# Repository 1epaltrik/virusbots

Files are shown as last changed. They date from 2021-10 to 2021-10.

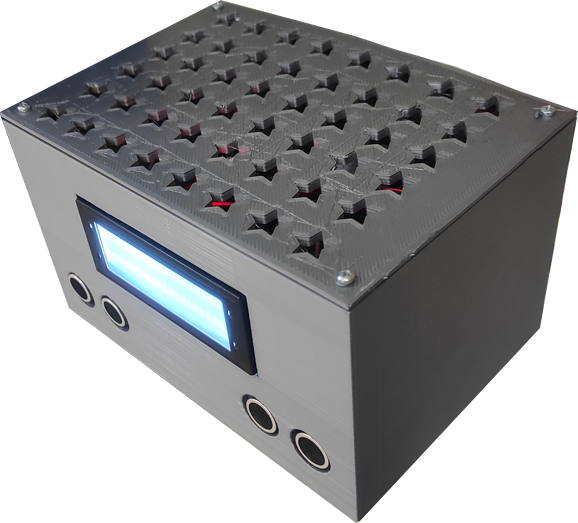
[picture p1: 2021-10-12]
VirusBots Case.png

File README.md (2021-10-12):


<p style="text-align: justify;">Το έργο μας αποτελείται από διάφορες τεχνολογίες οι οποίες όλες μαζί αποτελούν ένα σύστημα καταγραφής βεβαρημένης ατμόσφαιρας, που μπορεί να συμβάλλει στην παρακολούθηση του ιικού φορτίου στις σχολικές αίθουσες. Συγκεκριμένα οι επιμέρους λειτουργίες του είναι:</p>

<ul>
 	<li><strong> </strong><strong>Καταμέτρηση ατόμων</strong></li>
</ul>

<p style="text-align: justify; padding-left: 40px;">Καταγράφει πόσοι μαθητές βρίσκονται σε κάθε αίθουσα την κάθε στιγμή (ουσιαστικά χρησιμοποιείται ως παρουσιολόγιο). Χρησιμοποιήσαμε δύο Αισθητήρες Απόστασης Υπερήχων οι οποίοι συνδέονται σε ένα Arduino Mega. Ο Α αισθητήρας τοποθετήθηκε στην έξω πλευρά της τάξης ενώ ο Β στην μέσα πλευρά. Εάν ο Α αισθητήρας ενεργοποιηθεί πριν από τον Β σημαίνει ότι ένα άτομο εισήλθε μέσα στην αίθουσα. Αντίστοιχα εάν ενεργοποιηθεί πρώτα ο Β καταλαβαίνουμε πως ένα άτομο εξήλθε από την τάξη.</p>

<ul>
 	<li><strong>Έλεγχος αν η αίθουσα αερίζεται</strong></li>
</ul>
<p style="text-align: justify; padding-left: 40px;">Για να καταγράψουμε εάν η αίθουσα αερίζεται ελέγχουμε εάν ένα παράθυρο είναι ανοιχτό ή όχι. Η καταγραφή έγινε με την χρήση ενός μαγνητικού αισθητήρα (Magnetic Reed Switch), που συνδέεται σε ένα Arduino Mega. Ο μαγνητικός αισθητήρας αποτελείται από δύο μέρη: το ένα τοποθετείται στο κούφωμα ενώ το άλλο αντίστοιχα στο παράθυρο, έτσι ώστε να είναι σε επαφή. Όταν το παράθυρο ανοίξει, χάνεται η επαφή. Επομένως καταλαβαίνουμε πως το παράθυρο είναι ανοιχτό και η αίθουσα αερίζεται.</p>
&nbsp;
<ul>
 	<li><strong>Καταγραφή ποιότητας και επιπέδου ρύπανσης αέρα</strong></li>
</ul>

<p style="text-align: justify; padding-left: 40px;">Για την καταγραφή της <strong>ποιότητας και του επιπέδου ρύπανσης αέρα </strong> χρησιμοποιήθηκαν δύο (2) αισθητήρες. Για την μέτρηση:</p>

<ol>
 	<li style="list-style-type: none;">
<ol>
 	<li style="text-align: justify;">Της ποιότητας του αέρα χρησιμοποιήσαμε έναν αισθητήρα Ποιότητας Αέρα (CCS811). Ο αισθητήρας καταγράφει τα επίπεδα διοξειδίου του άνθρακα (CO<sub>2</sub>) και πτητικών οργανικών ενώσεων (tVOC).</li>
 	<li style="text-align: justify;">Του επιπέδου ρύπανσης του αέρα χρησιμοποιήσαμε έναν Particulate Matter Sensor PMS5003 ο οποίος ανιχνεύει τα μικροσωματίδια που είναι στην ατμόσφαιρα της αίθουσας. Γίνεται καταμέτρηση δύο διαστάσεων μικροσωματιδίων, των PM2.5 και PM10.</li>
</ol>
</li>
</ol>
<ul>
 	<li><strong>Καταγραφή θερμοκρασίας και υγρασίας αιθουσών</strong></li>
</ul>

<p style="text-align: justify;">Όλες οι τιμές που καταγράφονται με τα παραπάνω συστήματα αποστέλλονται μέσω Wi-Fi και του ESP8266 στο νέφος  και είναι προσβάσιμες μέσω διαδικτύου στην ιστοσελίδα <a href="http://www.thinkspeak.com">www.thinkspeak.com</a> στα 3 κανάλια μας <a href="https://thingspeak.com/channels/1507949/">https://thingspeak.com/channels/1507949/</a>, <a href="https://thingspeak.com/channels/1312761/">https://thingspeak.com/channels/1312761/</a>, <a href="https://thingspeak.com/channels/1507989/">https://thingspeak.com/channels/1507989/</a> καθώς χρησιμοποιήθηκε η τεχνολογία Internet of Things (IoT). Οι τιμές αυτές μπορούν να επεξεργασθούν προκειμένου να δώσουν στοιχεία για το κατά πόσο επηρεάζει η βεβαρημένη ατμόσφαιρα των αιθουσών (ανάλογα με τις συνθήκες) τις απουσίες των μαθητών. Το σύστημα καταγραφής βεβαρημένης ατμόσφαιρας τοποθετήθηκε σε 3 αίθουσες με διαφορετικό προσανατολισμό (βόρειο, νότιο και δυτικό αντίστοιχα), προκειμένου να είναι δυνατή η σύγκριση δεδομένων και η εξαγωγή χρήσιμων συμπερασμάτων.</p>
<p style="text-align: justify;">Η έρευνα που διεξήχθη, ο σχεδιασμός που έγινε, ο τρόπος που υλοποιήθηκαν οι διάφορες τεχνολογίες για την παρακολούθηση παραγόντων που μπορούν να επηρεάσουν το ιικό φορτίο στις σχολικές αίθουσες καθώς και το αναλυτικό εκπαιδευτικό υλικό που αναπτύχθηκε βρίσκονται στο αποθετήριο github. Σύνδεσμος github <a href="https://github.com/1epaltrik/virusbots">https://github.com/1epaltrik/virusbots </a></p>
<p style="text-align: justify;">Αναλυτικότερα, στον σύνδεσμο:</p>

<ul>
 	<li style="text-align: justify;"><a href="https://github.com/1epaltrik/virusbots/tree/master/docs">https://github.com/1epaltrik/virusbots/tree/master/docs</a> υπάρχει η έρευνα και η σχεδίαση-τρόπος υλοποίησης του έργου καθώς και το κόστος των υλικών του</li>
 	<li style="text-align: justify;"><a href="https://github.com/1epaltrik/virusbots/tree/master/docs/fylla_ergasias"><span style="color: #ff9900;">https://github.com/1epaltrik/virusbots/tree/master/docs/fylla_ergasias </span></a>υπάρχουν αναλυτικά φύλλα εργασίας για κάθε μέρος του έργου</li>
 	<li style="text-align: justify;"><span style="color: #ff9900;"><a href="https://github.com/1epaltrik/virusbots/tree/master/code">https://github.com/1epaltrik/virusbots/tree/master/code </a></span>υπάρχουν στους αντίστοιχους φακέλους τα αρχεία κώδικα Arduino (.ino), τα σχέδια Fritzing (.fzz) και τα τρισδιάστατα μοντέλα (.stl) του κουτιού που χρησιμοποιήθηκαν στο έργο</li>
</ul>
&nbsp;

Tο βίντεο με λεπτομέρειες του έργου, από την αρχή μέχρι και την ολοκλήρωσή του θα το βρείτε στην ιστοσελίδα: https://youtu.be/LB_R5pna_wI

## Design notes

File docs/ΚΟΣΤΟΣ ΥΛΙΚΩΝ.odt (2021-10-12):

Κόστος υλικών

Εξάρτημα | κόστος
3 Arduino Mega 2560 Rev3 | 127,50
Jumper Wires και καλώδια μεγαλύτερου μήκους | 25,00
Pin Header | 1,20
Νήμα PLA 2.85mm - 1kg | 25,00
3 ESP8266 WiFi Module | 17,40
3 ESP-01 Adapter Module 3.3-5V | 9,60
3 Οθόνες Basic 20x4 Character LCD | 29,70
3 LCD Display I2C Interface Module | 3,60
3 Πλακέτες Δοκιμών - 830 Οπές | 12,60
3 Tροφοδοτικά 9V 1A | 14,70
3 Magnetic Reed Switch | 9,00
6 Waveshare Υπέρηχοι Αισθητήρες Απόστασης | 23,40
3 SparkFun Αισθητήρες Ποιότητας Αέρα - CCS811 (https://grobotronics.com/sparkfun-air-quality-breakout-ccs811.html) | 78,00
3 Particulate Matter Sensor PMS5003 with Cable | 72,33
3 Particulate Matter Sensor Breakout | 10,50
3 Power Supply 5V | 15
Συνολικό κόστος | €479,53

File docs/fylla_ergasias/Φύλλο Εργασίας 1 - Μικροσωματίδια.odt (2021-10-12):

1^ο φύλλο εργασίας

Μέτρηση μικροσωματιδίων στον αέρα

1. Συγκεντρώστε τα εξής υλικά:

1 Arduino Mega

1 αισθητήρα σωματιδίων PMS-5003

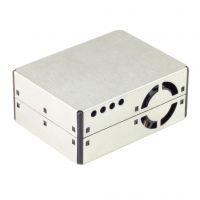
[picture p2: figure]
Particulate Matter Sensor PMS5003 with Cable

1 πλακέτα PMS-5003 BreakOut

1 καλωδιοταινία σύνδεσης του αισθητήρα στην πλακέτα

Καλώδια Jumper Wires

2. Συνδέστε τα υλικά που συγκεντρώσατε, υλοποιώντας το παρακάτω κύκλωμα:

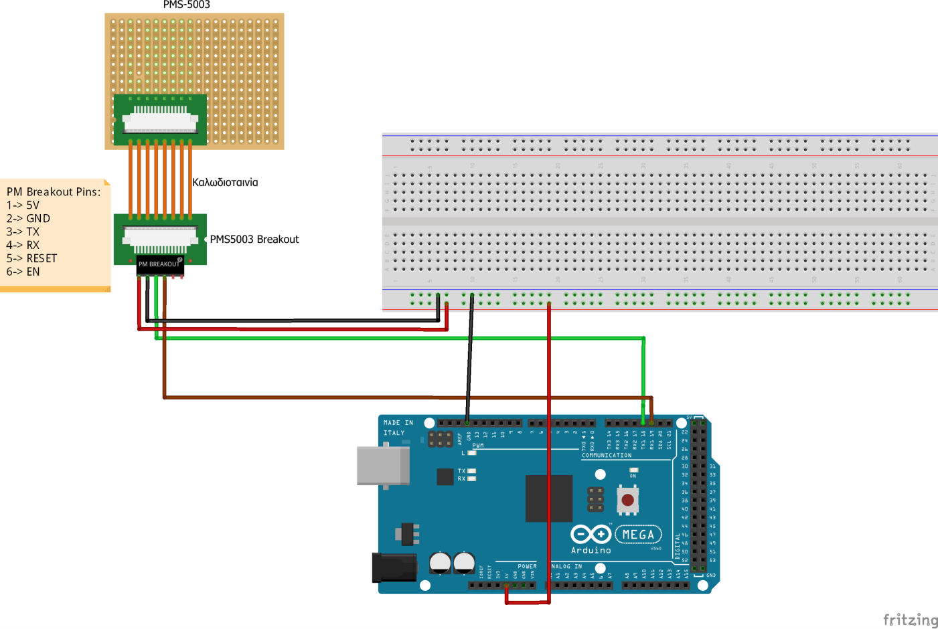
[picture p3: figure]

3. Στο Arduino IDE εγκαταστήστε την απαραίτητη βιβλιοθήκη "PMS Library".
4. Προγραμματίστε το Arduino έτσι ώστε να διαβάζει τα δεδομένα του αισθητήρα σωματιδίων PMS-5003 και να τα εμφανίζει στο Serial Monitor.

// 01. Μέτρηση μικροσωματιδίων PM1.0, PM2.5 και PM10.0

#include "PMS.h"

// το PMS5003 συνδέεται στο hardware Serial1 του Arduino Mega

PMS pms(Serial1);

PMS::DATA data;

void setup()

{

Serial.begin(9600);

Serial1.begin(9600);

Serial.println("hi");

}

void loop()

{

if (pms.read(data))

{

Serial.print("PM 1.0 (ug/m3): ");

Serial.println(data.PM_AE_UG_1_0);

Serial.print("PM 2.5 (ug/m3): ");

Serial.println(data.PM_AE_UG_2_5);

Serial.print("PM 10.0 (ug/m3): ");

Serial.println(data.PM_AE_UG_10_0);

Serial.println();

}

}

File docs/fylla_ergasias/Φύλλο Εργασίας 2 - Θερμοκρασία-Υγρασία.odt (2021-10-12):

2^ο φύλλο εργασίας

Μέτρηση θερμοκρασίας - υγρασίας

1. Συγκεντρώστε τα εξής υλικά:

1 Arduino Mega

1 αισθητήρα σωματιδίων PMS-5003

Particulate Matter Sensor PMS5003 with Cable

1 πλακέτα PMS-5003 BreakOut

1 καλωδιοταινία σύνδεσης του αισθητήρα στην πλακέτα

1 αισθητήρα θερμοκρασίας-υγρασίας DHT11

Καλώδια Jumper Wires

2. Συνδέστε τα υλικά που συγκεντρώσατε, υλοποιώντας το παρακάτω κύκλωμα:

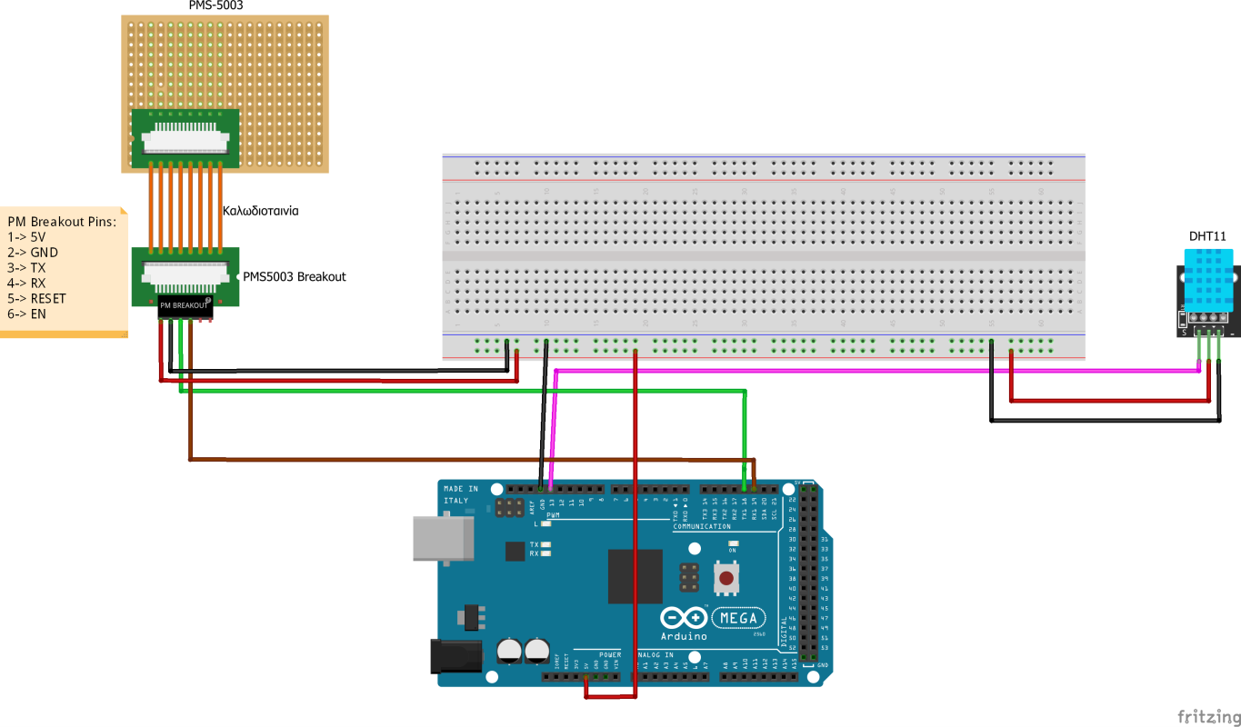
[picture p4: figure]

3. Στο Arduino IDE εγκαταστήστε την απαραίτητη βιβλιοθήκη "DHT sensor library".
4. Προγραμματίστε το Arduino έτσι ώστε να διαβάζει επιπλέον τα δεδομένα του αισθητήρα DHT11 (θερμοκρασία-υγρασία) και να τα εμφανίζει στο Serial Monitor κάθε 3 δευτερόλεπτα.

// 02. Προσθήκη μέτρησης Θερμοκρασίας και Υγρασίας

#include "PMS.h"

#include "DHT.h"

#define DHTPIN 13

#define DHTTYPE DHT11

DHT dht(DHTPIN, DHTTYPE);

PMS pms(Serial1);

PMS::DATA data;

unsigned long currentTime;

unsigned long previousTime1 = 0;

void setup()

{

dht.begin();

Serial.begin(9600);

Serial1.begin(9600);

Serial.println("hi");

}

void loop()

{

currentTime = millis();

float h = dht.readHumidity();

float t = dht.readTemperature();

if (pms.read(data))

{

Serial.print("PM 1.0 (ug/m3): ");

Serial.println(data.PM_AE_UG_1_0);

Serial.print("PM 2.5 (ug/m3): ");

Serial.println(data.PM_AE_UG_2_5);

Serial.print("PM 10.0 (ug/m3): ");

Serial.println(data.PM_AE_UG_10_0);

Serial.println();

}

// εμφάνιση μετρήσεων κάθε 3 sec

if( currentTime - previousTime1 >= 3000 )

{

Serial.print("Temperature: ");

Serial.println(t);

Serial.print("Humidity: ");

Serial.println(h);

Serial.println("--------------------------------");

previousTime1 = currentTime;

}

}

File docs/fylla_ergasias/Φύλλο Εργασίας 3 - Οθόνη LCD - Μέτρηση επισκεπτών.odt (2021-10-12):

3^ο φύλλο εργασίας

Σύνδεση οθόνης LCD - Μέτρηση επισκεπτών

1. Συγκεντρώστε τα εξής υλικά:

1 Arduino Mega

1 αισθητήρα σωματιδίων PMS-5003

Particulate Matter Sensor PMS5003 with Cable

1 πλακέτα PMS-5003 BreakOut

1 καλωδιοταινία σύνδεσης του αισθητήρα στην πλακέτα

1 αισθητήρα θερμοκρασίας-υγρασίας DHT11

1 οθόνη LCD (I2C) 20 χαρακτήρων και 4 γραμμών

2 αισθητήρες υπερήχων (απόστασης ) HC-SR04

Καλώδια Jumper Wires

2. Συνδέστε τα υλικά που συγκεντρώσατε, υλοποιώντας το παρακάτω κύκλωμα:

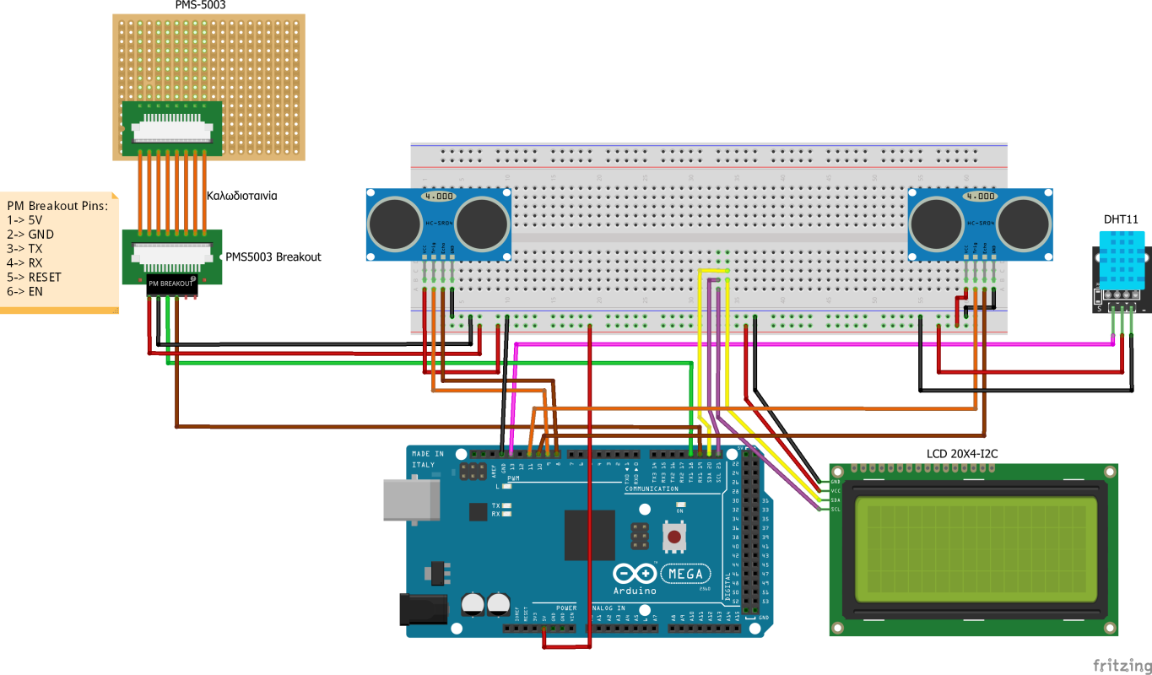
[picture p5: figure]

3. Στο Arduino IDE εγκαταστήστε τις απαραίτητες βιβλιοθήκες "LiquidCrystal I2C" και "NewPing".
4. Προγραμματίστε το Arduino έτσι ώστε να εμφανίζει τα δεδομένα των αισθητήρων στην οθόνη LCD.
5. Επίσης υλοποιήστε έναν αλγόριθμο μέτρησης επισκεπτών, χρησιμοποιώντας τους δύο αισθητήρες απόστασης. Ανάλογα με το ποιος από τους δύο αισθητήρες ενεργοποιείται πρώτος να καθορίζεται αν ο επισκέπτης εισέρχεται στην αίθουσα ή εξέρχεται από αυτήν. Ο συνολικός αριθμός ατόμων στην αίθουσα να εμφανίζεται στην οθόνη LCD.

// 03. Προσθήκη οθόνης LCD και μέτρηση επισκεπτών με 2 αισθητήρες υπερήχων

#include "PMS.h"

#include "DHT.h"

#include <LiquidCrystal_I2C.h>

#include <Wire.h>

#include <NewPing.h>

#define DHTPIN 13

#define DHTTYPE DHT11

#define MAX_DISTANCE 60 // Η μέγιστη απόσταση (σε cm) που ελέγχουν οι αισθητήρες

DHT dht(DHTPIN, DHTTYPE);

PMS pms(Serial1);

PMS::DATA data;

unsigned long currentTime;

unsigned long previousTime1 = 0;

NewPing sonar1 = NewPing(9, 8, MAX_DISTANCE);

NewPing sonar2 = NewPing(11, 10, MAX_DISTANCE);

LiquidCrystal_I2C lcd(0x27, 20, 4); // οθόνη LCD 20 χαρακτήρων και 4 γραμμών στη διεύθυνση 0x27

int sensor1 = 0;

int sensor2 = 0;

unsigned long t1 = 0;

unsigned long t2 = 0;

int visitors = 0;

int pmsData10 = 0;

int pmsData25 = 0;

int pmsData100 = 0;

void setup()

{

dht.begin();

Serial.begin(9600);

Serial1.begin(9600);

Serial.println("hi");

lcd.init();

lcd.backlight();

lcd.setCursor(0,0);

lcd.print("1st EPAL of Trikala");

lcd.setCursor(0,1);

lcd.print("Visitors:");

}

void loop()

{

currentTime = millis();

float h = dht.readHumidity();

float t = dht.readTemperature();

if (pms.read(data))

{

pmsData10 = data.PM_AE_UG_1_0;

pmsData25 = data.PM_AE_UG_2_5;

pmsData100 = data.PM_AE_UG_10_0;

}

if( currentTime - previousTime1 >= 3000 )

{

Serial.print("PM 1.0 (ug/m3): ");

Serial.println(pmsData10);

Serial.print("PM 2.5 (ug/m3): ");

Serial.println(pmsData25);

Serial.print("PM 10.0 (ug/m3): ");

Serial.println(pmsData100);

Serial.println();

Serial.print("Temperature: ");

Serial.println(t);

Serial.print("Humidity: ");

Serial.println(h);

Serial.println("--------------------------------");

previousTime1 = currentTime;

}

// Μέτρηση επισκεπτών

long distance1 = sonar1.ping_cm();

long distance2 = sonar2.ping_cm();

if( distance1 > 0 && distance1 < MAX_DISTANCE )

{

t1 = millis();

sensor1 = 1;

}

else

{

sensor1 = 0;

}

if( distance2 > 0 && distance2 < MAX_DISTANCE )

{

t2 = millis();

sensor2 = 1;

}

else

{

sensor2 = 0;

}

if( sensor1 == 0 && sensor2 == 0 )

{

if( t1 > 0 && t2 > 0 )

{

if( t2 > t1 )

{

visitors++;

}

else if( t1 > t2 )

{

if( visitors > 0 )

{

visitors--;

}

}

t1 = t2 = 0;

}

}

lcd.setCursor(10,1);

lcd.print(" ");

lcd.setCursor(10,1);

lcd.print(visitors);

}

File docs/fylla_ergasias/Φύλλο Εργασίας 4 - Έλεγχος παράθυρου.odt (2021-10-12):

4^ο φύλλο εργασίας

Έλεγχος παράθυρου

1. Συγκεντρώστε τα εξής υλικά:

1 Arduino Mega

1 αισθητήρα σωματιδίων PMS-5003

Particulate Matter Sensor PMS5003 with Cable

1 πλακέτα PMS-5003 BreakOut

1 καλωδιοταινία σύνδεσης του αισθητήρα στην πλακέτα

1 αισθητήρα θερμοκρασίας-υγρασίας DHT11

1 οθόνη LCD (I2C) 20 χαρακτήρων και 4 γραμμών

2 αισθητήρες υπερήχων (απόστασης ) HC-SR04

1 μαγνητικός διακόπτης (magnetic reed switch)

Καλώδια Jumper Wires

2. Συνδέστε τα υλικά που συγκεντρώσατε, υλοποιώντας το παρακάτω κύκλωμα:

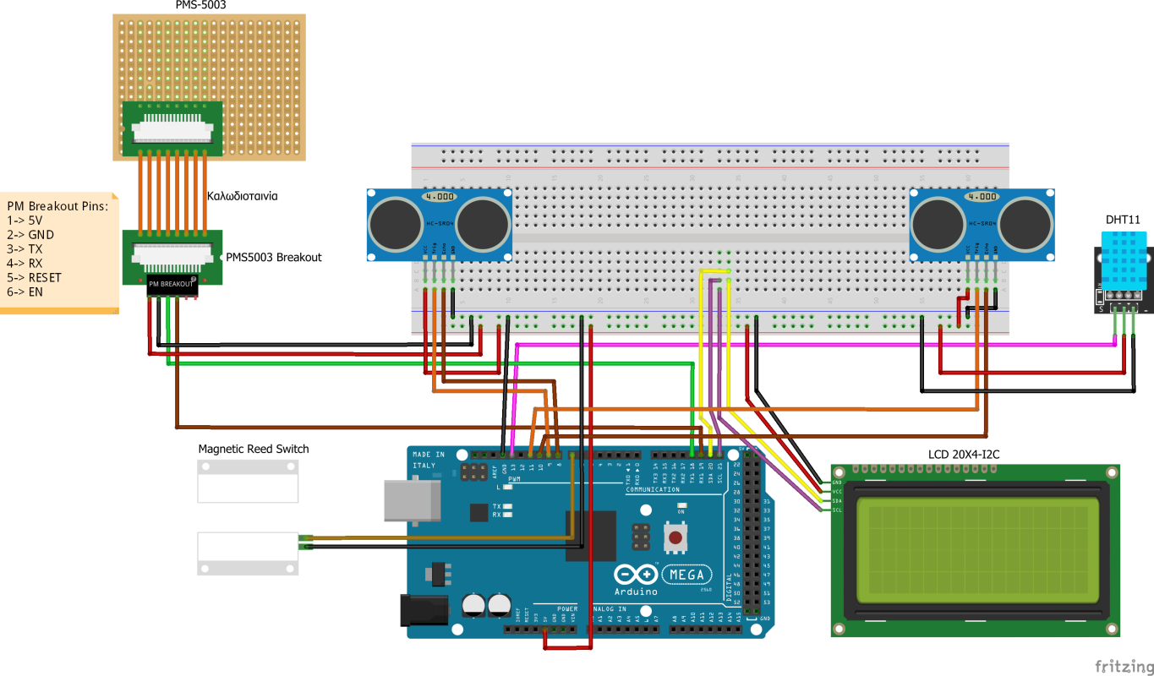
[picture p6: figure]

3. Προσαρμόστε το μαγνητικό διακόπτη στο παράθυρο και προγραμματίστε το Arduino έτσι ώστε να ελέγχει αν το παράθυρο είναι ανοικτό ή κλειστό, εμφανίζοντας και το ανάλογο μήνυμα στη σειριακή οθόνη.

// 04. Προσθήκη ελέγχου για ανοικτό παράθυρο με μαγνητικό αισθητήρα

#include "PMS.h"

#include "DHT.h"

#include <LiquidCrystal_I2C.h>

#include <Wire.h>

#include <NewPing.h>

#define DHTPIN 13

#define DHTTYPE DHT11

#define MAX_DISTANCE 60 // Η μέγιστη απόσταση (σε cm) που ελέγχουν οι αισθητήρες

#define WINDOW_SENSOR_PIN 7

DHT dht(DHTPIN, DHTTYPE);

PMS pms(Serial1);

PMS::DATA data;

unsigned long currentTime;

unsigned long previousTime1 = 0;

NewPing sonar1 = NewPing(9, 8, MAX_DISTANCE);

NewPing sonar2 = NewPing(11, 10, MAX_DISTANCE);

LiquidCrystal_I2C lcd(0x27, 20, 4); // οθόνη LCD 20 χαρακτήρων και 4 γραμμών στη διεύθυνση 0x27

int sensor1 = 0;

int sensor2 = 0;

unsigned long t1 = 0;

unsigned long t2 = 0;

int visitors = 0;

int pmsData10 = 0;

int pmsData25 = 0;

int pmsData100 = 0;

int windowState;

void setup()

{

dht.begin();

Serial.begin(9600);

Serial1.begin(9600);

Serial.println("hi");

lcd.init();

lcd.backlight();

lcd.setCursor(0,0);

lcd.print("1st EPAL of Trikala");

lcd.setCursor(0,1);

lcd.print("Visitors:");

pinMode(WINDOW_SENSOR_PIN, INPUT_PULLUP); // set arduino pin to input pull-up mode

}

void loop()

{

currentTime = millis();

float h = dht.readHumidity();

float t = dht.readTemperature();

if (pms.read(data))

{

pmsData10 = data.PM_AE_UG_1_0;

pmsData25 = data.PM_AE_UG_2_5;

pmsData100 = data.PM_AE_UG_10_0;

}

windowState = digitalRead(WINDOW_SENSOR_PIN);

if( currentTime - previousTime1 >= 3000 )

{

Serial.print("PM 1.0 (ug/m3): ");

Serial.println(pmsData10);

Serial.print("PM 2.5 (ug/m3): ");

Serial.println(pmsData25);

Serial.print("PM 10.0 (ug/m3): ");

Serial.println(pmsData100);

Serial.println();

Serial.print("Temperature: ");

Serial.println(t);

Serial.print("Humidity: ");

Serial.println(h);

Serial.println();

if (windowState == HIGH)

{

Serial.println("The window is open");

}

else

{

Serial.println("The window is closed");

}

Serial.println("--------------------------------");

previousTime1 = currentTime;

}

// Μέτρηση επισκεπτών

long distance1 = sonar1.ping_cm();

long distance2 = sonar2.ping_cm();

if( distance1 > 0 && distance1 < MAX_DISTANCE )

{

t1 = millis();

sensor1 = 1;

}

else

{

sensor1 = 0;

}

if( distance2 > 0 && distance2 < MAX_DISTANCE )

{

t2 = millis();

sensor2 = 1;

}

else

{

sensor2 = 0;

}

if( sensor1 == 0 && sensor2 == 0 )

{

if( t1 > 0 && t2 > 0 )

{

if( t2 > t1 )

{

visitors++;

}

else if( t1 > t2 )

{

if( visitors > 0 )

{

visitors--;

}

}

t1 = t2 = 0;

}

}

lcd.setCursor(10,1);

lcd.print(" ");

lcd.setCursor(10,1);

lcd.print(visitors);

}

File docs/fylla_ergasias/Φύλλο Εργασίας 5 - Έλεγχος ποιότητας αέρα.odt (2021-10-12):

5^ο φύλλο εργασίας

Έλεγχος ποιότητας αέρα (CO2 και tVOC)

1. Συγκεντρώστε τα εξής υλικά:

1 Arduino Mega

1 αισθητήρα σωματιδίων PMS-5003

Particulate Matter Sensor PMS5003 with Cable

1 πλακέτα PMS-5003 BreakOut

1 καλωδιοταινία σύνδεσης του αισθητήρα στην πλακέτα

1 αισθητήρα θερμοκρασίας-υγρασίας DHT11

1 οθόνη LCD (I2C) 20 χαρακτήρων και 4 γραμμών

2 αισθητήρες υπερήχων (απόστασης ) HC-SR04

1 μαγνητικός διακόπτης (magnetic reed switch)

1 αισθητήρας ποιότητας αέρα CCS811

1 σταθεροποιητή τάσης (voltage regulator) LD1117

1 τροφοδοτικό 5V

Καλώδια Jumper Wires

2. Κολλήστε τις ακίδες στον αισθητήρα ποιότητας αέρα CCS811
3. Συνδέστε τα υλικά που συγκεντρώσατε, υλοποιώντας το παρακάτω κύκλωμα:

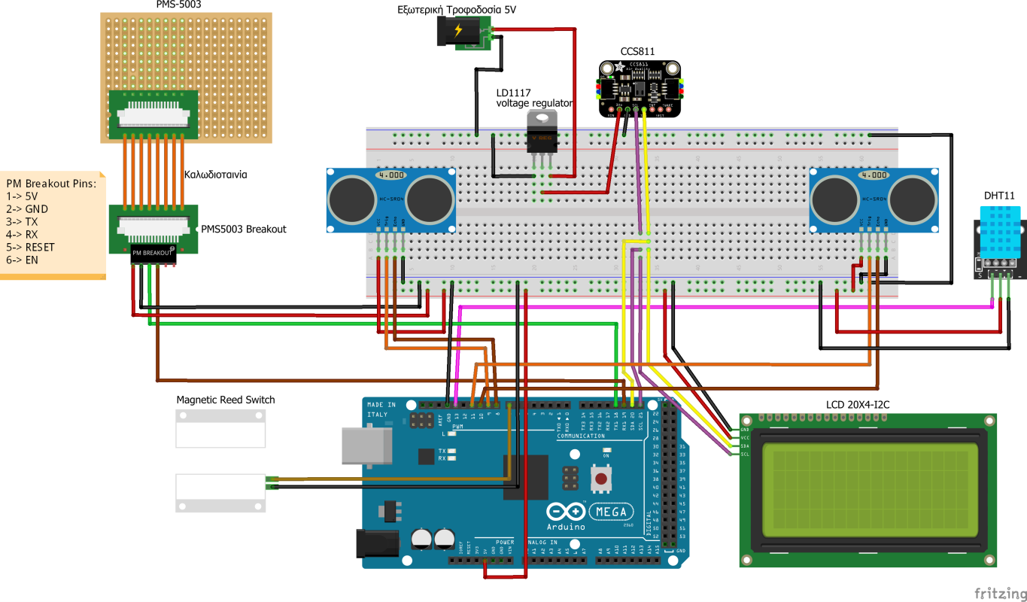
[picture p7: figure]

4. Στο Arduino IDE εγκαταστήστε την απαραίτητη βιβλιοθήκη "SparkFun CCS811 Arduino Library".
5. Προγραμματίστε το Arduino έτσι ώστε να εμφανίζει και τις μετρήσεις (διοξείδιο του άνθρακα και πτητικές οργανικές ενώσεις) του αισθητήρα CCS811 .

// 05. Προσθήκη μέτρηση της ποιότητας του αέρα με τον αισθητήρα CCS811

#include "PMS.h"

#include "DHT.h"

#include <LiquidCrystal_I2C.h>

#include <Wire.h>

#include <NewPing.h>

#include "SparkFunCCS811.h"

#define DHTPIN 13

#define DHTTYPE DHT11

#define MAX_DISTANCE 60 // Η μέγιστη απόσταση (σε cm) που ελέγχουν οι αισθητήρες

#define WINDOW_SENSOR_PIN 7

#define CCS811_ADDR 0x5B //Default I2C Address

//#define CCS811_ADDR 0x5A //Alternate I2C Address

DHT dht(DHTPIN, DHTTYPE);

PMS pms(Serial1);

PMS::DATA data;

unsigned long currentTime;

unsigned long previousTime1 = 0;

NewPing sonar1 = NewPing(9, 8, MAX_DISTANCE);

NewPing sonar2 = NewPing(11, 10, MAX_DISTANCE);

LiquidCrystal_I2C lcd(0x27, 20, 4); // οθόνη LCD 20 χαρακτήρων και 4 γραμμών στη διεύθυνση 0x27

CCS811 mySensor(CCS811_ADDR);

int sensor1 = 0;

int sensor2 = 0;

unsigned long t1 = 0;

unsigned long t2 = 0;

int visitors = 0;

int pmsData10 = 0;

int pmsData25 = 0;

int pmsData100 = 0;

int windowState;

int co2 = 0;

int tvoc = 0;

void setup()

{

dht.begin();

Serial.begin(9600);

Serial1.begin(9600);

Serial.println("hi");

lcd.init();

lcd.backlight();

lcd.setCursor(0,0);

lcd.print("1st EPAL of Trikala");

lcd.setCursor(0,1);

lcd.print("Visitors:");

pinMode(WINDOW_SENSOR_PIN, INPUT_PULLUP); // set arduino pin to input pull-up mode

// ccs811

Wire.begin(); // Initialize I2C Hardware

if( mySensor.begin() == false )

{

lcd.println("CCS811 Error...");

while(true); // τέλος...

}

}

void loop()

{

currentTime = millis();

float h = dht.readHumidity();

float t = dht.readTemperature();

if (pms.read(data))

{

pmsData10 = data.PM_AE_UG_1_0;

pmsData25 = data.PM_AE_UG_2_5;

pmsData100 = data.PM_AE_UG_10_0;

}

windowState = digitalRead(WINDOW_SENSOR_PIN);

// διάβασμα CCS811

if( mySensor.dataAvailable() )

{

mySensor.readAlgorithmResults();

co2 = mySensor.getCO2();

tvoc = mySensor.getTVOC();

}

if( currentTime - previousTime1 >= 3000 )

{

Serial.print("PM 1.0 (ug/m3): ");

Serial.println(pmsData10);

Serial.print("PM 2.5 (ug/m3): ");

Serial.println(pmsData25);

Serial.print("PM 10.0 (ug/m3): ");

Serial.println(pmsData100);

Serial.println();

Serial.print("Temperature: ");

Serial.println(t);

Serial.print("Humidity: ");

Serial.println(h);

Serial.println();

if (windowState == HIGH)

{

Serial.println("The window is open");

}

else

{

Serial.println("The window is closed");

}

lcd.setCursor(0, 2);

lcd.print("CO2=");

lcd.print(co2);

lcd.setCursor(0, 3);

lcd.print("tVOC=");

lcd.print(tvoc);

Serial.println("--------------------------------");

previousTime1 = currentTime;

}

// Μέτρηση επισκεπτών

long distance1 = sonar1.ping_cm();

long distance2 = sonar2.ping_cm();

if( distance1 > 0 && distance1 < MAX_DISTANCE )

{

t1 = millis();

sensor1 = 1;

}

else

{

sensor1 = 0;

}

if( distance2 > 0 && distance2 < MAX_DISTANCE )

{

t2 = millis();

sensor2 = 1;

}

else

{

sensor2 = 0;

}

if( sensor1 == 0 && sensor2 == 0 )

{

if( t1 > 0 && t2 > 0 )

{

if( t2 > t1 )

{

visitors++;

}

else if( t1 > t2 )

{

if( visitors > 0 )

{

visitors--;

}

}

t1 = t2 = 0;

}

}

lcd.setCursor(10,1);

lcd.print(" ");

lcd.setCursor(10,1);

lcd.print(visitors);

}

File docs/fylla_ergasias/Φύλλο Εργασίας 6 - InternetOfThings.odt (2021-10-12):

6^ο φύλλο εργασίας

1^η δραστηριότητα

Δημιουργία λογαριασμού στο Thingspeak.com

1. Μπείτε στο https://thingspeak.com/ και πατήστε το κουμπί:
2. Απαιτείται λογαριασμός στο MathWorks. Για να δημιουργήσετε έναν, πατήστε "Create One".
3. Συμπληρώστε την παρακάτω φόρμα:

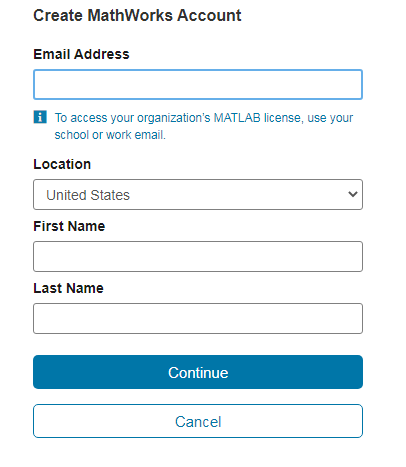
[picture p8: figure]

4. Με το λογαριασμό MathWorks συνδεθείτε στο thingspeak και πατήστε:
5. Συμπληρώστε τη φόρμα έτσι ώστε να φαίνονται οι τιμές PM2.5, PM10, CO2, tVOC, πλήθος ατόμων, αερισμός, θερμοκρασία και υγρασία, όπως στην παρακάτω εικόνα:

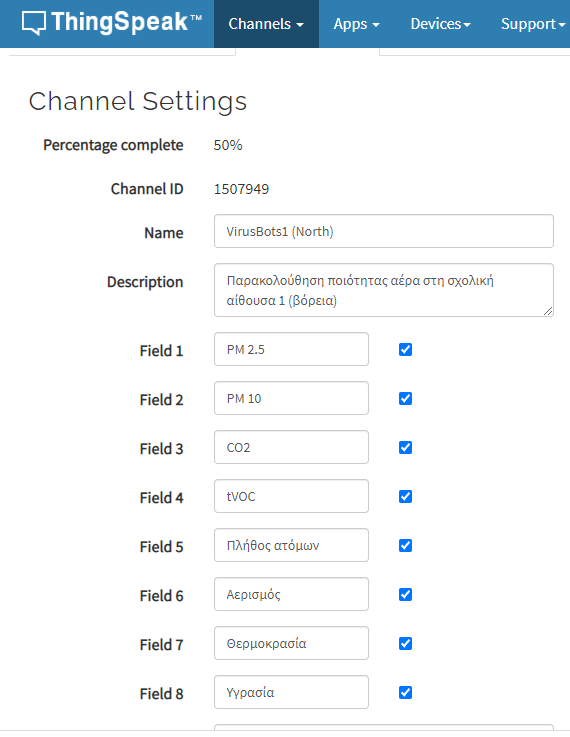
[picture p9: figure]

6. Καθορίστε τον τρόπο πρόσβασης στη σελίδα σας:

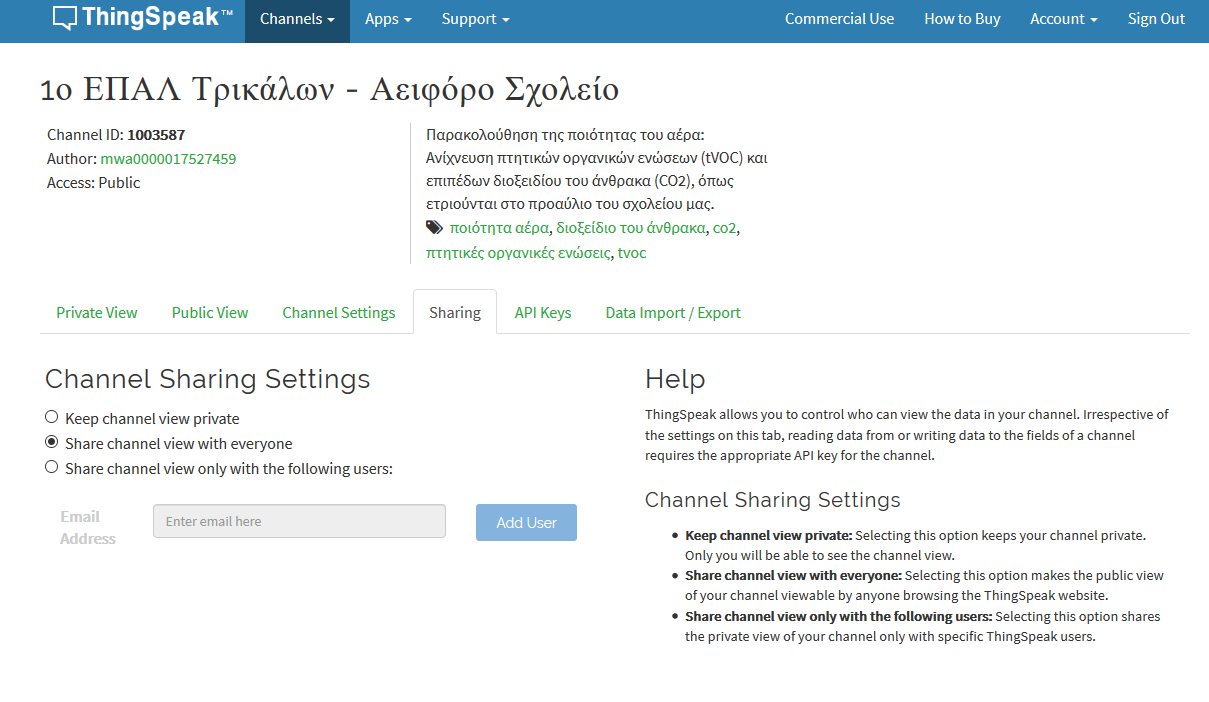
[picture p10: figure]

7. Στην καρτέλα “API Keys” φαίνονται οι κωδικοί πρόσβασης. Ο κωδικός “Write API Key” είναι απαραίτητος και θα χρησιμοποιηθεί (στον παρακάτω κώδικα Arduino) για την αποστολή των δεδομένων σας στο site.
8. Στην καρτέλα “Public View” καθορίζεται ο τρόπος εμφάνισης των δεδομένων. Για κάθε πεδίο πατήστε στο εικονίδιο με το μολύβι για να δείτε τις επιλογές εμφάνισης των γραφημάτων.

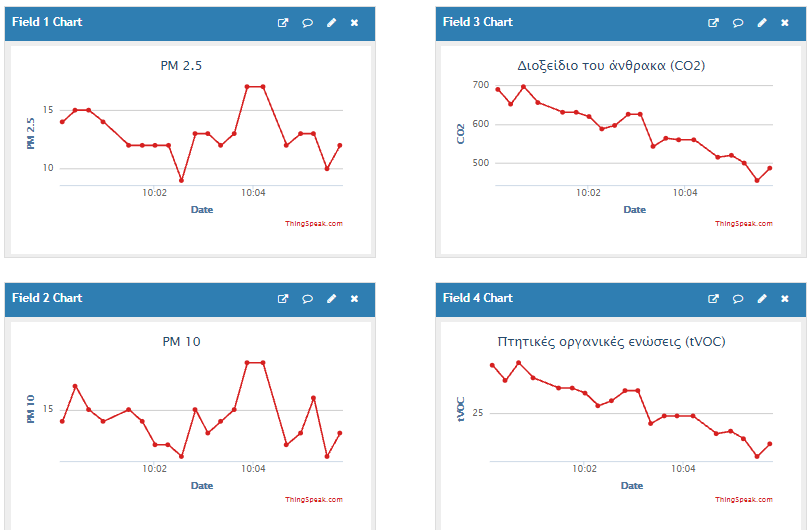
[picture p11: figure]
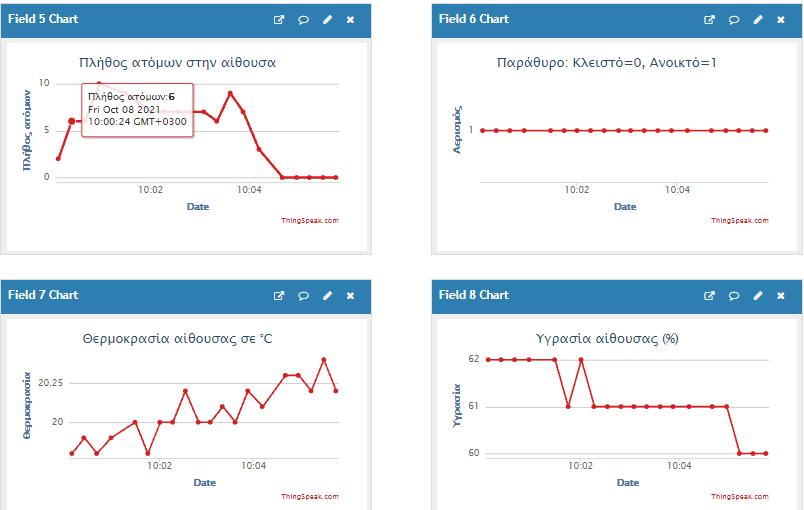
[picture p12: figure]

2^η δραστηριότητα

Σύνδεση στο διαδίκτυο – Internet Of Things

1. Συγκεντρώστε τα εξής υλικά:

1 Arduino Mega

1 αισθητήρα σωματιδίων PMS-5003

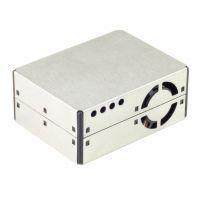
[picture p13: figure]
Particulate Matter Sensor PMS5003 with Cable

1 πλακέτα PMS-5003 BreakOut

1 καλωδιοταινία σύνδεσης του αισθητήρα στην πλακέτα

1 αισθητήρα θερμοκρασίας-υγρασίας DHT11

1 οθόνη LCD (I2C) 20 χαρακτήρων και 4 γραμμών

2 αισθητήρες υπερήχων (απόστασης ) HC-SR04

1 μαγνητικός διακόπτης (magnetic reed switch)

1 αισθητήρας ποιότητας αέρα CCS811

1 σταθεροποιητή τάσης (voltage regulator) LD1117

1 τροφοδοτικό 5V

1 ESP8266 WiFi Module

1 πλακέτα Adapter Module για το ESP8266

Καλώδια Jumper Wires

2. Συνδέστε τα υλικά που συγκεντρώσατε, υλοποιώντας το παρακάτω κύκλωμα:

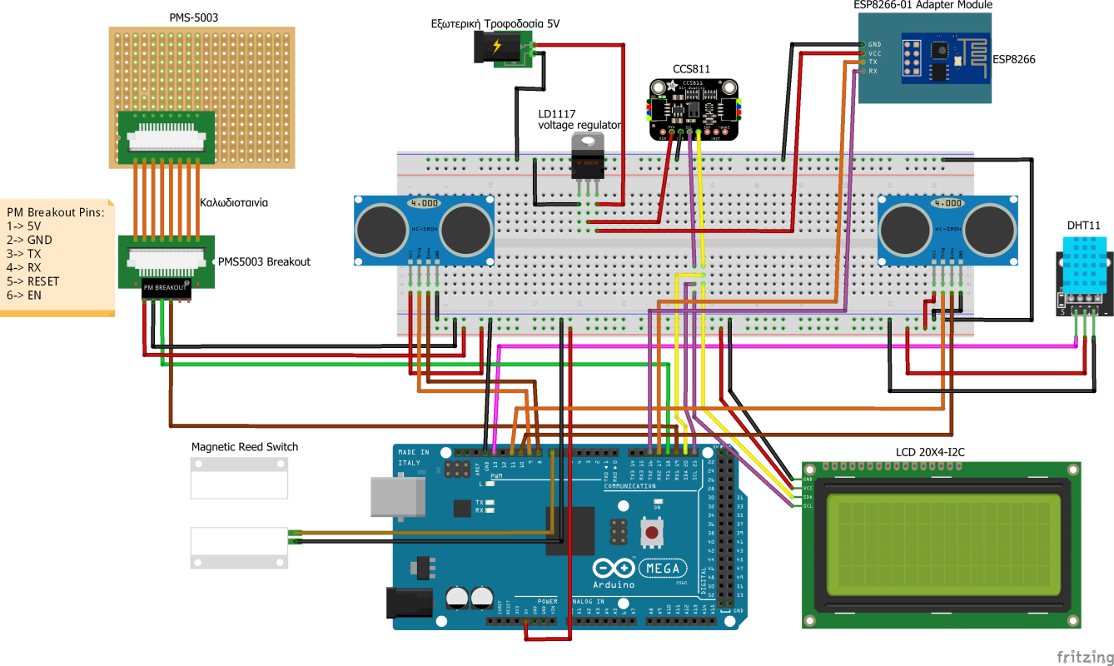
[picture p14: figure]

3. Στο Arduino IDE εγκαταστήστε τη βιβλιοθήκη " WiFiEsp".
4. Προγραμματίστε το Arduino έτσι ώστε να συνδέεται στο δίκτυο WiFi της περιοχής εγκατάστασης και να στέλνει όλα τα δεδομένα (θερμοκρασία, υγρασία, σωματίδια PM, CO2, tVOC, πλήθος ατόμων στην αίθουσα καθώς αν το παράθυρο είναι ανοικτό) στο thingspeak.com

// 06. Προσθήκη πρόσβασης στο διαδίκτυο με το ESP8266-01 WiFi module

#include "PMS.h"

#include "DHT.h"

#include <LiquidCrystal_I2C.h>

#include <Wire.h>

#include <NewPing.h>

#include "SparkFunCCS811.h"

#include "WiFiEsp.h"

#define DHTPIN 13

#define DHTTYPE DHT11

#define MAX_DISTANCE 60 // Η μέγιστη απόσταση (σε cm) που ελέγχουν οι αισθητήρες

#define WINDOW_SENSOR_PIN 7

#define CCS811_ADDR 0x5B //Default I2C Address

//#define CCS811_ADDR 0x5A //Alternate I2C Address

DHT dht(DHTPIN, DHTTYPE);

PMS pms(Serial1);

PMS::DATA data;

unsigned long currentTime;

unsigned long previousTime1 = 0;

NewPing sonar1 = NewPing(9, 8, MAX_DISTANCE);

NewPing sonar2 = NewPing(11, 10, MAX_DISTANCE);

LiquidCrystal_I2C lcd(0x27, 20, 4); // οθόνη LCD 20 χαρακτήρων και 4 γραμμών στη διεύθυνση 0x27

CCS811 mySensor(CCS811_ADDR);

// Initialize the Ethernet client object

WiFiEspClient client;

int sensor1 = 0;

int sensor2 = 0;

unsigned long t1 = 0;

unsigned long t2 = 0;

int visitors = 0;

int pmsData10 = 0;

int pmsData25 = 0;

int pmsData100 = 0;

int windowState;

int co2 = 0;

int tvoc = 0;

// Κωδικοί WiFi

char ssid[] = "ΧΧΧΧΧΧΧΧ"; // WiFi SSID (name)

char pass[] = "ΧΧΧΧΧΧΧΧ"; // WiFi password

int status = WL_IDLE_STATUS;

// IP του thingspeak.com

char server[] = "184.106.153.149";

// Write API Key του λογαριασμού στο thingspeak στην καρτέλα API Keys

char writeKey[] = "ΧΧΧΧΧΧΧΧΧΧΧΧΧΧΧΧ";

void setup()

{

dht.begin();

Serial.begin(115200);

Serial1.begin(9600);

Serial.println("hi");

lcd.init();

lcd.backlight();

lcd.setCursor(0,0);

lcd.print("1st EPAL of Trikala");

lcd.setCursor(0,1);

lcd.print("Visitors:");

pinMode(WINDOW_SENSOR_PIN, INPUT_PULLUP); // set arduino pin to input pull-up mode

// ccs811

Wire.begin(); // Initialize I2C Hardware

if( mySensor.begin() == false )

{

lcd.println("CCS811 Error...");

while(true); // τέλος...

}

// Αρχικοποίηση του serial3 για το ESP module

// ΠΡΟΣΟΧΗ: TX->RX3 ΚΑΙ RX->TX3

Serial2.begin(115200);

// initialize ESP module

WiFi.init(&Serial2);

// έλεγχος για το ESP8266

if( WiFi.status() == WL_NO_SHIELD )

{

Serial.println("WiFi shield not present");

while(true); // τέλος...

}

// σύνδεση στο WiFi

while( WiFi.status() != WL_CONNECTED )

{

Serial.print("Attempting to connect to: ");

Serial.println(ssid);

status = WiFi.begin(ssid, pass);

}

Serial.println("You're connected to the wifi");

Serial.println();

}

void loop()

{

currentTime = millis();

float h = dht.readHumidity();

float t = dht.readTemperature();

if (pms.read(data))

{

pmsData10 = data.PM_AE_UG_1_0;

pmsData25 = data.PM_AE_UG_2_5;

pmsData100 = data.PM_AE_UG_10_0;

}

windowState = digitalRead(WINDOW_SENSOR_PIN);

// διάβασμα CCS811

if( mySensor.dataAvailable() )

{

mySensor.readAlgorithmResults();

co2 = mySensor.getCO2();

tvoc = mySensor.getTVOC();

}

if( currentTime - previousTime1 >= 3000 )

{

Serial.print("PM 1.0 (ug/m3): ");

Serial.println(pmsData10);

Serial.print("PM 2.5 (ug/m3): ");

Serial.println(pmsData25);

Serial.print("PM 10.0 (ug/m3): ");

Serial.println(pmsData100);

Serial.println();

Serial.print("Temperature: ");

Serial.println(t);

Serial.print("Humidity: ");

Serial.println(h);

Serial.println();

if (windowState == HIGH)

{

Serial.println("The window is open");

}

else

{

Serial.println("The window is closed");

}

lcd.setCursor(0, 2);

lcd.print("CO2=");

lcd.print(co2);

lcd.setCursor(0, 3);

lcd.print("tVOC=");

lcd.print(tvoc);

Serial.println("--------------------------------");

previousTime1 = currentTime;

}

// Μέτρηση επισκεπτών

long distance1 = sonar1.ping_cm();

long distance2 = sonar2.ping_cm();

if( distance1 > 0 && distance1 < MAX_DISTANCE )

{

t1 = millis();

sensor1 = 1;

}

else

{

sensor1 = 0;

}

if( distance2 > 0 && distance2 < MAX_DISTANCE )

{

t2 = millis();

sensor2 = 1;

}

else

{

sensor2 = 0;

}

if( sensor1 == 0 && sensor2 == 0 )

{

if( t1 > 0 && t2 > 0 )

{

if( t2 > t1 )

{

visitors++;

}

else if( t1 > t2 )

{

if( visitors > 0 )

{

visitors--;

}

}

t1 = t2 = 0;

}

}

lcd.setCursor(10,1);

lcd.print(" ");

lcd.setCursor(10,1);

lcd.print(visitors);

}

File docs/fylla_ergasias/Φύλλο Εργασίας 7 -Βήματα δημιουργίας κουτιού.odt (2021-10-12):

7^ο φύλλο εργασίας

Σχεδίαση κουτιού για αποθήκευση συστήματος παρακολούθησης ιικού φορτίου στις σχολικές αίθουσες

Στη διαδικτυακή πλατφόρμα Tinkercad: https://www.tinkercad.com, καλείστε να σχεδιάσετε ένα κουτί που στο εσωτερικό του θα τοποθετείται ένα κύκλωμα Arduino για την παρακολούθηση της ποιότητας αέρα. Η μορφή του μπορεί να είναι όπως αυτή που ακολουθεί (Σχήμα 1).

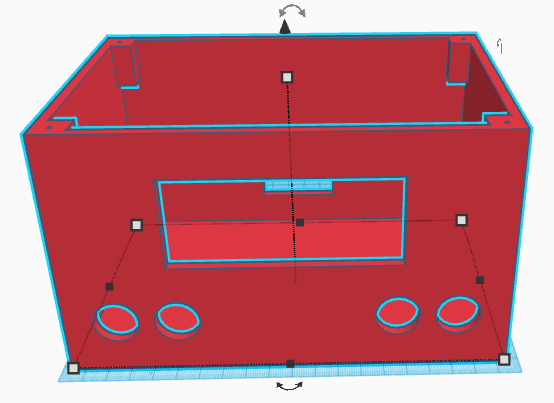
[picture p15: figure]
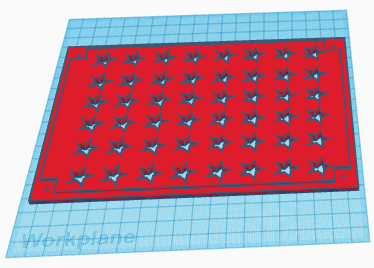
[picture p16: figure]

Σχήμα 1

Τα μέρη από τα οποία θα αποτελείται είναι:

1. Το βασικό κουτί
2. Ένα διαχωριστικό μεταξύ του βασικού συστήματος Arduino και των αισθητήρων, προκειμένου να επιτυγχάνονται πιο ακριβείς μετρήσεις από την απομόνωσή τους.
3. Ένα καπάκι που θα βιδώνει στο βασικό κουτί με τα κατάλληλα ανοίγματα ώστε να είναι εφικτές σωστές μετρήσεις

1η Δραστηριότητα

Δημιουργία κουτιού

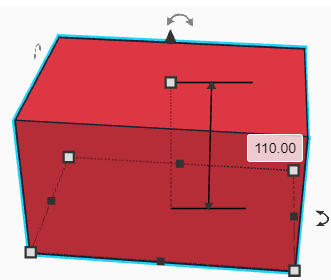
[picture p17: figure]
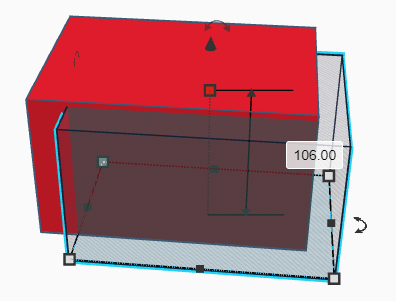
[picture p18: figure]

Δημιουργήστε ένα box 190x130x110mm | Δημιουργήστε ένα Hole box 182x122x106mm

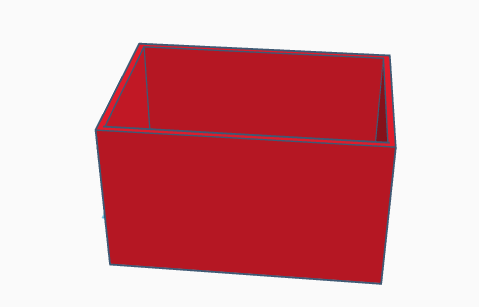
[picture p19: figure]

Να γίνει στοίχιση των 2 σχημάτων ως εξής | Επιλέξτε Group
Δημιουργήστε ένα Hole box 99x41x4mm | Εξυψώστε το κατά 50mm και περιστρέψτε το κατά 90^ο.

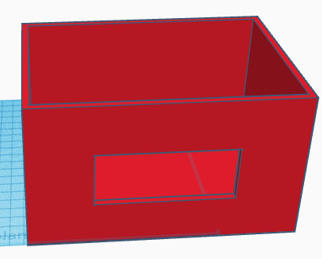
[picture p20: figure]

Στοιχίστε τα 2 σχήματα που έχετε στην οθόνη σας όπως φαίνεται στο σχήμα | Ομαδοποιήστε τα 2 σχήματα
Δημιουργία πατούρας για τη στήριξη του διαχωριστικού

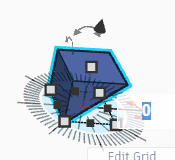
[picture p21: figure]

Επιλέξτε ως νέο σχήμα το Wedge | Περιστρέψτε το όπως στο σχήμα

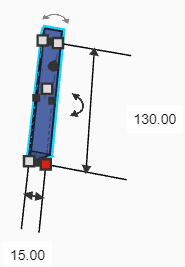
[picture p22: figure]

Αλλάξτε τις διαστάσεις του σε 20x130x15mm | Εξυψώστε το κατά 35mm

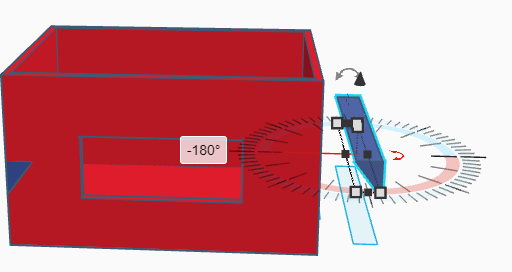
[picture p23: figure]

Δημιουργήστε έναν κλώνο του Wedge και τοποθετήστε το νέο σχήμα στην αντίθετη πλευρά του κουτιού | Ομαδοποιήστε όλα τα υπάρχοντα σχήματα
Δημιουργία στηριγμάτων για να βιδωθεί το καπάκι

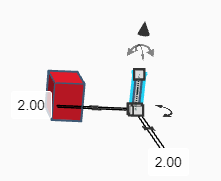
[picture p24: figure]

Δημιουργήστε ένα box 14x14x20mm Δημιουργήστε έναν hole cylinder 2x2x20mm | Στοιχίστε τα δύο σχήματα μεταξύ τους και ομαδοποιήστε τα. Δημιουργήστε άλλους 3 κλώνους του νέου σχήματος

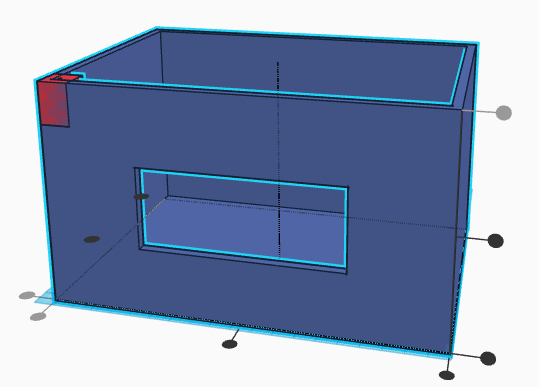
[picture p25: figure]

Τοποθετείστε τα νέα σχήματα στις 4 κορυφές του κουτιού όπως στο σχήμα και ομαδοποιήστε τα
Δημιουργία εγκοπών για την τοποθέτηση των αισθητήρων Ultrasonic
Δημιουργήστε δύο hole cylinder 20x20x20mm που τα άκρα τους θα απέχουν 46mm και ομαδοποιήστε τα | Δημιουργήστε έναν κλώνο τον 2 κυλίνδρων


Εξυψώστε τα Hole Cylinder κατά 15mm και μεταφέρετέ τα κατά 12mm δεξιά. Επαναλάβετε την ίδια διαδικασία για την άλλη πλευρά του κουτιού

2η Δραστηριότητα

Δημιουργία διαχωριστικού


Δημιουργήστε ένα box 180x120x3mm | Δημιουργήστε ένα Cylinder 7x7x15mm
Δημιουργήστε έναν κλώνο του κυλίνδρου | Δημιουργήστε ένα Hole box 110x20x20mm


Ομαδοποιήστε όλα τα σχήματα | Δημιουργήστε δύο Hole box 10x10x5mm στις άκρες του μεγάλου σχήματος και ομαδοποιήστε τα

3η Δραστηριότητα

Δημιουργία καπακιού

Δημιουργήστε ένα box 190x130x4mm | Δημιουργήστε ένα star 15x15x4mm
Κλωνοποιήστε το αστέρι άλλες 7 φορές και ομαδοποιήστε τη νέα συστοιχία αστεριών | Κλωνοποιήστε τη συστοιχία αστεριών άλλες 5 φορές


Δημιουργήστε τέσσερα Hole Cylinder 2x2x5mm και τοποθετήστε τα στις άκρες του καπακιού σε απόσταση 7mm από τις δύο άκρες | Δημιουργήστε έναν κλώνο του κουτιού και «αφήστε το στο περιθώριο»


Κάντε Hole τον κλώνο | Στοιχίστε απόλυτα τα 2 σχήματα και εξυψώστε το καπάκι κατά 108mm


Ομαδοποιήστε τα 2 σχήματα | Περιστρέψτε το νέο σχήμα κατά 180^ο και κατεβάστε το κατά 108mm

4η Δραστηριότητα

Δημιουργία εσοχής περάσματος καλωδίων


Δημιουργήστε ένα Hole box 40x5x20mm | Στοιχίστε το τελευταίο σχήμα που δημιουργήσατε στο πίσω μέρος του κουτιού και εξυψώστε το κατά 20mm
Ομαδοποιήστε αυτά τα 2 σχήματα.

5η Δραστηριότητα

Τοποθέτηση υλικών

Εφόσον ολοκληρώσατε τα πρώτα 6 φύλλα εργασίας και εκτυπώσατε το κουτί, το διαχωριστικό και το καπάκι, τοποθετήστε και σταθεροποιήστε (π.χ. με θερμόκολλα) τα υλικά Arduino ως εξής:

- στο κάτω μέρος του κουτιού το Arduino Mega, το Breadboard με τα υλικά που φέρουν και τους 2 αισθητήρες απόστασης HC-SR04
- από την πίσω εσοχή του κουτιού θα πρέπει να βγάλετε την τροφοδοσία 12V (του Arduino), την τροφοδοσία 5V (ESP 8266 και CCS811) και το Magnetic Reed Switch
- την οθόνη στο μπροστινό μέρος του κουτιού με την κατάλληλη στήριξη
- το διαχωριστικό θα μπει ως μεσοτοιχία για τη μόνωση των αισθητήρων
- πάνω από το διαχωριστικό τοποθετήστε τα PMS5003, DHT11, CCS811 και ESP8266
- το καπάκι στο πάνω μέρος του κουτιού με 4 βίδες για σταθερότητα


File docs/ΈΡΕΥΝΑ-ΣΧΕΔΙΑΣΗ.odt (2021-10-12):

ΕΡΕΥΝΑ

Μελέτη υπάρχουσας κατάστασης

Ιικό φορτίο στις σχολικές αίθουσες

## Ποιότητα αέρα

Η ποιότητα του αέρα καθορίζεται από την ποσότητα επιβλαβών ουσιών στην ατμόσφαιρα. Μετράται με τη χρήση του Δείκτη Ποιότητας Αέρα (ΔΠΑ) και χρησιμοποιούνται τόσο τα επίγεια όργανα όσο και οι δορυφόροι για τον προσδιορισμό του επιπέδου της ρύπανσης στο ΔΠΑ από 0 έως 500. Το 0-50 είναι το ασφαλέστερο και το 301-500 είναι το πιο επικίνδυνο.

Παραβλέπεται συχνά η ποιότητα του αέρα εσωτερικού χώρου, ωστόσο πρέπει να σημειωθεί ότι η κακή ποιότητα του αέρα μπορεί να είναι μερικές φορές εξίσου ή πιο επιβλαβής από την κακή ποιότητα του εξωτερικού αέρα. Οι χημικές ουσίες που εκπέμπονται μεταξύ άλλων από εκτυπωτές, φρέσκα χρώματα, έπιπλα και καθαριστικά, μπορούν και επηρεάζουν την ποιότητα αέρα οποιουδήποτε εσωτερικού χώρου.

Οι σημαντικότερες μέθοδοι που χρησιμοποιούνται για την εκτίμηση της ποιότητας του αέρα του εσωτερικού περιβάλλοντος συνοψίζονται ως εξής, (Λαγούδη, 1996):

- Καταγραφή των χαρακτηριστικών του κτιρίου (προσανατολισμός, περιοχή, χρήση, κυκλοφοριακό πρόβλημα στους κοντινούς δρόμους, εξωτερικές πηγές ρύπανσης, ηλικία του κτιρίου, δομικά υλικά του κτιρίου, γεωμετρικά χαρακτηριστικά του κτιρίου, γενικές δραστηριότητες των ενοίκων του κτιρίου, συσκευές εξοπλισμού, συχνότητα καθαρισμού των κτιρίων και προϊόντα καθαρισμού)
- Συλλογή δεδομένων που αφορούν στην αντίδραση των εργαζομένων στις περιβαλλοντικές συνθήκες (συστήματα μηχανικού αερισμού, θέρμανσης και ψύξης, ύπαρξη συστήματος ανακύκλωσης και ύγρανσης του αέρα, ύπαρξη φίλτρων, συχνότητα καθαρισμού και συντήρησης των συστημάτων μηχανικού αερισμού, κλπ)
- Μετρήσεις των σημαντικότερων παραγόντων που επηρεάζουν την ποιότητα αέρα εσωτερικού περιβάλλοντος (επιφάνεια δωματίου, επιφάνεια παραθύρων, επιφάνεια χνουδωτών υλικών, αριθμός ενοίκων, αριθμός και είδη ηλεκτρικών συσκευών, δομικά υλικά και υλικά επίπλωσης των δωματίων, συνθήκες φωτισμού, έλεγχος θορύβου)

Συγκέντρωση πλήθους σε κλειστούς χώρους

Έρευνες δείχνουν πως η συγκέντρωση ατόμων μέσα σε κλειστούς χώρους και ιδιαιτέρως η υψηλή συγκέντρωση αυξάνει εκθετικά την μόλυνση του αέρα. Σε γραφεία, αίθουσες, μαγαζιά καθώς και σε μπαρ και κλειστές ταβέρνες, οι ανθρώπινοι οργανισμοί έχουν σημαντικό αντίκτυπο στην ποιότητα του αέρα, αφού επιβαρύνουν την ατμόσφαιρα με επιπλέον διοξείδιο του άνθρακα. Επιπροσθέτως δεν αυξάνει μόνο τα επίπεδα CO2, μα πολύ σημαντική είναι και η εκθετική αύξηση μικροσωματιδίων και μικροοργανισμών.

Ο άνθρωπος στην μάχη του για επιβίωση συνεχώς κάνει καύσεις γλυκογόνου με οξυγόνο με αποτέλεσμα ως “καυσαέρια” της διαδικασίας αυτής να εκπνέει διοξείδιο του άνθρακα στο γύρω περιβάλλον. Αυτή η ποσότητα δεν είναι ικανή να μας προκαλέσει κάποιο πρόβλημα στην αναπνοή σε ένα πολυσύχναστο κλειστό μαγαζί ή εμπορικό κατάστημα, μα είναι ικανή να επιβαρύνει την ατμόσφαιρα, με ό,τι και αν συνεπάγεται αυτό.

Τον τελευταίο χρόνο καταλάβαμε όλοι πόσο σημαντική και επικίνδυνη μπορεί να αποβεί η συγκέντρωση πολλών ατόμων μέσα σε μία αίθουσα. Λόγω του κορονοϊού έχει απαγορευτεί ο συνωστισμός μέσα σε κλειστούς χώρους.

Έρευνες έχουν δείξει πως η εκπνοή του ανθρώπου εκτός από διοξείδιο του άνθρακα και υδρατμούς περιέχει και πληθώρα μικροοργανισμών και μικροσωματιδίων. Ως μικροργανισμός εννοείται οποιοδήποτε μικρόβιο, ιός ή βακτηρίδιο. Οι άνθρωποι παραμένοντας σε έναν κλειστό χώρο για αρκετή ώρα που δεν αερίζεται τον πλουτίζουν με μικροοργανισμούς που αιωρούνται στην ατμόσφαιρα. Ως επί το πλείστον δεν μας επηρεάζουν ούτε στο ελάχιστο, μα διαπιστώνουμε με την φρίκη του κορονοϊού πόσο σημαντικό -και τραγικό- μπορεί να αποβεί αυτό. Επομένως, συνοψίζοντας διαπιστώνουμε όλοι πως η υψηλή συγκέντρωση ατόμων (συνωστισμός), μπορεί όντως να επιβαρύνει την ποιότητα αέρα και να την επηρεάσει.

Επιπτώσεις χαμηλή ποιότητας αέρα στα άτομα

Μπορεί να προκαλεί έκπληξη σε πολλούς από εμάς το γεγονός ότι ο αέρας σε έναν αστικό δρόμο με μέτρια κίνηση μπορεί στην πραγματικότητα να είναι πιο καθαρός από τον αέρα στο σαλόνι μας. (http://ihcp.jrc.ec.europa.eu/our_databases/airmex)Πρόσφατες μελέτες (http://ihcp.jrc.ec.europa.eu/our_databases/airmex) δείχνουν ότι ορισμένοι βλαβεροί ατμοσφαιρικοί ρύποι μπορεί να υπάρχουν σε υψηλότερες συγκεντρώσεις σε εσωτερικούς χώρους παρά σε εξωτερικούς. Κατά το παρελθόν, δινόταν πολύ λιγότερη προσοχή στην ατμοσφαιρική ρύπανση σε εσωτερικούς χώρους σε σύγκριση με την ατμοσφαιρική ρύπανση σε εξωτερικούς χώρους, ιδίως σε σύγκριση με τη ρύπανση από τις εκπομπές της βιομηχανίας και των μεταφορών. Ωστόσο, κατά τα τελευταία χρόνια οι απειλές από την έκθεση στην ατμοσφαιρική ρύπανση σε εσωτερικούς χώρους έχουν γίνει πιο εμφανείς.

Φανταστείτε ένα φρεσκοβαμμένο σπίτι, διακοσμημένο με καινούρια έπιπλα... Ή έναν χώρο εργασίας με βαριά μυρωδιά καθαριστικών προϊόντων... Η ποιότητα του αέρα στα σπίτια μας, στους χώρους εργασίας ή σε άλλους δημόσιους χώρους ποικίλλει σημαντικά, αναλόγως του υλικού που χρησιμοποιήθηκε για την κατασκευή και τον καθαρισμό του, τον σκοπό του δωματίου, καθώς και του τρόπου που το χρησιμοποιούμε και το αερίζουμε.

Η κακή ποιότητα του αέρα στους εσωτερικούς χώρους μπορεί να είναι ιδιαιτέρως επιβλαβής για ευαίσθητες ομάδες όπως τα παιδιά, οι ηλικιωμένοι και τα άτομα με καρδιοαγγειακές και χρόνιες παθήσεις του αναπνευστικού συστήματος όπως το άσθμα.

Μερικοί από τους κύριους ατμοσφαιρικούς ρύπους στους εσωτερικούς χώρους είναι το ραδόνιο (ένα ραδιενεργό αέριο που σχηματίζεται στο έδαφος), ο καπνός του τσιγάρου, τα αέρια ή τα σωματίδια από την κατανάλωση καυσίμων, από χημικά ή αλλεργιογόνα. Το μονοξείδιο του άνθρακα, τα διοξείδια του αζώτου, τα σωματίδια και οι πτητικές οργανικές ενώσεις μπορεί να βρεθούν τόσο σε εξωτερικούς όσο και σε εσωτερικούς χώρους.

Μετάδοση κορωνοϊού σε κλειστούς χώρους

Η αερομεταφερόμενη μετάδοση του SARS (https://www.cnn.gr/tag/sars-cov-2)- (https://www.cnn.gr/tag/sars-cov-2)CoV (https://www.cnn.gr/tag/sars-cov-2)- (https://www.cnn.gr/tag/sars-cov-2)2 (https://www.cnn.gr/tag/sars-cov-2) (https://www.cnn.gr/tag/sars-cov-2)έχει σημαντικό ρόλο στη διασπορά του ιού στους σύμφωνα με τους ερευνητές της επιστήμης των αερολυμάτων.

Οι σχετικές μελέτες έχουν καταλήξει στο συμπέρασμα πως ενώ η πιθανότητα αερομεταφερόμενης μετάδοσης σε εξωτερικούς χώρους είναι εξαιρετικά χαμηλή, στους εσωτερικούς χώρους, και δη σε εκείνους με υψηλή συνάθροιση ατόμων, ακόμη και η χρήση μάσκας προσώπου προσφέρει περιορισμένη προστασία.

«Η έρευνα για τις αερομεταφερόμενες ασθένειες πριν από την τρέχουσα πανδημία είχε επικεντρωθεί κυρίως σε ‘'βίαια'' φαινόμενα εκπνοής, όπως το φτάρνισμα και ο βήχας. Λιγότερη προσοχή είχε δοθεί στη μετάδοση αερολύματος (aerosol), αλλά υπάρχουν σημαντικοί λόγοι να υποψιαζόμαστε, ότι αυτός ο τρόπος μετάδοσης παίζει πολύ σημαντικό ρόλο στην υψηλή μεταδοτικότητα της covid-19», ανέφερε ο Κωνσταντίνος Σιούτας, καθηγητής στο Τμήμα Πολιτικών Μηχανικών και Μηχανικών Περιβάλλοντος και κάτοχος της έδρας Fred Champion στο Πανεπιστήμιο της Νότιας Καλιφόρνιας (USC), σε διαδικτυακή διάλεξη με θέμα «Ο Covid-19 από τη σκοπιά της επιστήμης των aerosol», που έδωσε κατόπιν πρόσκλησης της Πολυτεχνικής Σχολής του ΑΠΘ.

Ανάγκη αερισμού εσωτερικών χώρων

Η μάχη κατά της COVID-19 σημαίνει επενδύσεις εκατομμυρίων στην έρευνα και πολύ περιοριστικά μέτρα για την καθημερινή ζωή. Όμως εξαρτάται επίσης από μια κίνηση εντελώς απλή και που δεν κοστίζει τίποτα: το άνοιγμα των παραθύρων.

Ο αερισμός των κλειστών δωματίων μειώνει τον κίνδυνο μετάδοσης του κορωνοϊού μέσω πολύ μικρών σταγονιδίων που εκπνέει ένας άνθρωπος ο οποίος έχει μολυνθεί από τον ιό, υπογραμμίζει η πλειονότητα των ειδικών.

Αυτά τα σύννεφα ιικών σωματιδίων, τα επονομαζόμενα αεροζόλ, θεωρείται ότι μπορεί να παραμένουν στον αέρα για μακρά διαστήματα που μπορεί να φθάνουν έως και αρκετές ώρες. Εξ ου και η σημασία της ανανέωσης του εσωτερικού αέρα και της δημιουργίας ρευμάτων αέρα.

«Γνωρίζουμε όλοι πολύ καλά ένα άλλο αεροζόλ, τον καπνό του τσιγάρου. Όταν έχετε έναν καπνιστή σε ένα δωμάτιο, τι κάνετε; Ανοίγετε το παράθυρο για να φύγει το σύννεφο του καπνού! Με το αόρατο νέφος των αεροζόλ του κορονοϊού, πρέπει να κάνε το ίδιο πράγμα», εξηγεί στο Γαλλικό Πρακτορείο ο επιδημιολόγος Αντουάν Φλαό.

Οι αίθουσες θα πρέπει να αερίζονται πλήρως για τουλάχιστον 15 λεπτά πριν την έναρξη της λειτουργίας τους.

## Ιικό φορτίο και θερμοκρασία

Σε εντατικούς ρυθμούς συνεχίζονται οι εργασίες Το Αριστοτέλειο Πανεπιστήμιο Θεσσαλονίκης εξετάζει την πορεία της πανδημίας του κορωνοϊού στην χώρα μας μέσω του υπολογιστικού μοντέλου που ετοιμάζει το ENVELAB. Συγκεκριμένα αναλύει δεδομένα για να φτιάξουμε ένα συγκεκριμένο μοντέλο. Στόχος τους είναι να λάβουν υπόψη και παραμέτρους που επηρεάζουν το ιικό φορτίο. Το ιικό φορτίο μπορεί να επηρεαστεί και από περιβαλλοντικές παραμέτρους πχ την θερμοκρασία, την υγρασία (όπως προκύπτει από μετρήσεις σε Κίνα, Κορέα) και την υπεριώδη ακτινοβολία (ηλιοφάνεια). Το ΑΠΘ προσπαθεί να συλλέξει στοιχεία για αυτές τις παραμέτρους και να δημιουργήσει συντελεστές που θα το συνδυάζουν με τις περιβαλλοντικές συνθήκες ώστε να υπολογίσει την αλλαγή της μεταδοτικότητας. Για παράδειγμα ελπίζει πως με την ηλιοφάνεια σε πιο ζεστές περιοχές θα έχουμε λιγότερα κρούσματα», όπως δήλωσε στον «Τύπο Θεσσαλονίκης» ο καθηγητής Χημικών Μηχανικών του ΑΠΘ, Δημοσθένης Σαρηγιάννης.

## Ιικό φορτίο και Υγρασία αέρα

Σύμφωνα με τον Wolkoff (2018) “υπάρχει μια μακροχρόνια διαφωνία σχετικά με την υγρασία του αέρα εσωτερικού χώρου και την αντιληπτή ποιότητα αέρα εσωτερικού χώρου (IAQ) και τις σχετικές επιπτώσεις στην υγεία”.

Η υγρασία (υδρατμοί), πολλές φορές ευνοεί τη μετάδοση και επιβίωση των ιών, αλλά η σχέση μεταξύ υγρασίας, θερμοκρασίας και της δυναμικής του ιού και του αερολύματος είναι πολύπλοκη, η οποία τελικά εξαρτάται από τον μεμονωμένο τύπο ιού και τις φυσικές / χημικές του ιδιότητες.

## Ποιότητα εσωτερικού αέρα και CO2

Σε γραφεία και παρόμοιους χώρους εργασίας, οι άνθρωποι έχουν καθοριστικό αντίκτυπο στην ποιότητα του εσωτερικού αέρα - δηλαδή μέσω των ουσιών που εκπέμπουν (π.χ. CO₂). Χρησιμοποιώντας μέτρηση διοξειδίου του άνθρακα, η ποιότητα του αέρα σε αυτά τα δωμάτια μπορεί να αξιολογηθεί υποκειμενικά με αξιοπιστία. Κατά κανόνα, οι αυξημένες συγκεντρώσεις διοξειδίου του άνθρακα έχουν αρνητικό αντίκτυπο στις ικανότητες προσοχής

Για τη μέτρηση του CO2, είναι συνήθως λογικό να πραγματοποιείται μια μακροπρόθεσμη μέτρηση σε μια εργάσιμη ημέρα. Στη συνέχεια, μπορείτε να χρησιμοποιήσετε μια αξιολόγηση μέσω λογισμικού για να αναλύσετε σε ποια ώρα της ημέρας επιτυγχάνονται υψηλές συγκεντρώσεις και εάν το σύστημα κλιματισμού παρέχει τον κατάλληλο ρυθμό ανταλλαγής αέρα.
Μπορούν επίσης να εξαχθούν συμπεράσματα σχετικά με τις συνήθειες αερισμού του δωματίου από τον χρήστη του με βάση τη συγκέντρωση CO2 (Εικόνα 1).


Εικόνα 1. Επιπτώσεις συγκέντρωσης CO2 (Voultherm, 2021)

## Αιωρούμενα σωματίδια

Πρόκειται για μία μίξη ατμοσφαιρικών ρύπων με επικίνδυνα για την υγεία συστατικά δηλαδή βαρέα μέταλλα (μόλυβδος,κάδμιο,αρσενικό και νικέλιο), πολυκυκλικούς αρωματικούς υδρογονάνθρακες, διοξίνες, οργανοχλωριωμένα εντομοκτόνα.

Επιπτώσεις στον άνθρωπο

Τα αιωρούμενα σωματίδια έχουν άμεσες και χρόνιες επιπτώσεις στον ανθρώπινο οργανισμό. Σύμφωνα με επιδημιολογικές μελέτες, τα σωματίδια σχετίζονται με αυξημένη θνησιμότητα και νοσηρότητα (Schlesinger, 1995; Harrison and Yin, 2000; Green, 2003). Συγκεκριμένα, τα αιωρούμενα σωματίδια εισέρχονται στον ανθρώπινο οργανισμό με την αναπνοή και εναποτίθενται στο αναπνευστικό σύστημα (ανώτερο και κατώτερο), προκαλώντας άμεσες επιπτώσεις σε αυτό, όπως βρογχίτιδα και πνευμονία, αλλά και καρδιακά προβλήματα και επιδείνωση χρόνιων αποφρακτικών νόσων του αναπνευστικού συστήματος. Το μέγεθος του σωματιδίου παίζει πολύ σημαντικό ρόλο αναφορικά με τα προβλήματα της υγείας, καθώς καθορίζει τη θέση εναπόθεσής του στην αναπνευστική οδό. Τα μεγάλα σωματίδια PM10 έχουν την τάση να εναποτίθενται στην άνω θωρακική χώρα (μύτη και λάρυγγα), ενώ τα μικρότερα PM2.5 τείνουν να εισχωρούν βαθύτερα στους πνεύμονες και ειδικότερα στην κυψελιδική περιοχή (Εικόνα 2).


Εικόνα 2. Ταχύτητα πτώσης αιωρούμενων σωματιδίων σε σχέση με τη διάμετρό τους (Ruzer & Harley, 2005)

## Καταμέτρηση ατόμων

Για την καταμέτρηση των ατόμων σε χώρους και αίθουσες, μπορούμε να τοποθετήσουμε έναν άνθρωπο στην πόρτα ώστε να μετράει πόσοι και ποιοι εισέρχονται, αντίστοιχα και για αυτούς που εξέρχονται. Σε μεγαλύτερους χώρους όπως σούπερ μάρκετ, αλυσίδες καταστημάτων και εμπορικών κέντρων λόγω της υψηλής κινητικότητας και μεγάλων αριθμό ατόμων ως λύση είναι η πρόσληψη περισσοτέρων ατόμων για την διευκόλυνση της καταμέτρησης.

Για ευνόητους λόγους, τέτοιοι τρόποι καταμέτρησης ατόμων δεν είναι συμβατοί με την πραγματικότητα του 21ου αιώνα (υψηλή κατανάλωση πόρων, ανθρώπινου δυναμικού, ακρίβεια καταμέτρησης λιγότερη του 100% λόγω ανθρώπινου παράγοντα κλπ). Συνήθως χρησιμοποιούνται από δύο αισθητήρες κίνησης σε κάθε πόρτα. Ο ένας είναι τοποθετημένος στην μία πλευρά και σκοπός του είναι η καταμέτρηση των ατόμων που εισέρχονται μέσα, ενώ ο δεύτερος ‘δουλεύει’ στο αντίστοιχο αντικείμενο για την έξοδο των ατόμων. Το λογισμικό που χρησιμοποιείται, παίρνει τις πληροφορίες που του δίνουν οι αισθητήρες, αφαιρεί τα άτομα που εξήλθαν από τα άτομα που εισήλθαν στο χώρο και το αποτέλεσμα της πράξης είναι ο αριθμός των ατόμων που βρίσκονται μέσα την παρούσα την στιγμή.

## Τεχνολογία Internet of Things (IoT).

Το κοινό χαρακτηριστικό που έχουν οι «έξυπνες» συσκευές, όπως μια smart TV, ένα βραχιόλι γυμναστικής και άλλες υπηρεσίες φωνητικής βοήθειας τύπου Alexa, είναι ότι όλες περιλαμβάνονται στην έννοια του Internet of Things.

Το IoT επί της ουσίας αποτελείται από μια πληθώρα αντικειμένων, υλικών, εργαλείων και εξοπλισμών, τα οποία μέσα από τη σύνδεσή τους σε δίκτυα «ανοίγουν ένα διάλογο» μεταξύ τους και αλληλεπιδρούν με ανταλλαγές σημάτων και δεδομένων. Μεταξύ, όμως, αυτών των δεδομένων περιλαμβάνονται και τα λεγόμενα προσωπικά δεδομένα.

Πεδία εφαρμογής του Internet of Things

Το Internet of Things, δηλαδή, βρίσκει εφαρμογή σε διάφορα πεδία της ζωής, όπως είναι η υγεία χάρη σε «έξυπνες» συσκευές για πρόβλεψη και διάγνωση, η κινητικότητα (κυρίως μέσω της έννοιας του smart city), το σπίτι (με τις ενέργειες οικιακού αυτοματισμού), η βιομηχανία, η γεωργία, οι οικονομικές συναλλαγές κ.λπ. Χάρη στους πολλούς τομείς εφαρμογής του, το Διαδίκτυο των πραγμάτων παρουσιάζει αρκετά πλεονεκτήματα.

Ωστόσο, δεν είναι λίγοι αυτοί που εκφράζουν παράλληλα και τις ανησυχίες τους σχετικά με την ασφάλεια και την προστασία των προσωπικών δεδομένων. Μάλιστα, η συγκεκριμένη συζήτηση ήρθε ακόμη περισσότερο στην επιφάνεια, πριν από περίπου ένα χρόνο, λόγω του Γενικού Κανονισμού Προστασίας Δεδομένων, το λεγόμενο GDPR, που ψήφισε το Ευρωπαϊκό Κοινοβούλιο.

Επομένως, η έννοια της διαφάνειας και της ιδιωτικότητας είναι οι δύο κεντρικοί προβληματισμοί των περισσότερων χρηστών του Διαδικτύου. Με άλλα λόγια, προκειμένου να αισθανόμαστε ασφαλείς όσον αφορά την αξιοποίηση των προσωπικών μας δεδομένων, θα πρέπει τα τελευταία να επεξεργάζονται με τρόπο νόμιμο και διαφανή, πράγμα που προϋποθέτει ότι το πρόσωπο που τα επεξεργάζεται πρέπει να εφαρμόζει εξίσου διαφανείς και εύκολα προσβάσιμες πολιτικές.

Οφέλη τεχνολογίας Internet of Things (IoT).

To IoT χωρίζεται σε δύο βασικές κατηγορίες. Στην πρώτη έχουμε την καταναλωτική αγορά και τις διάφορες συνδεδεμένες συσκευές και στη δεύτερη τις συσκευές βιομηχανικού αυτοματισμού. Στη δεύτερη κατηγορία κατατάσσονται οι περιπτώσεις του CERN και η ναυτιλία που θα δούμε πιο κάτω, αλλά και κάθε άλλη μεγάλη βιομηχανική εγκατάσταση (τα εργοστάσια παραγωγής ενέργειας είναι ένα καλό παράδειγμα). Ωστόσο, ο καταναλωτής χρειάζεται παραδείγματα βγαλμένα μέσα από τη ζωή του για να αντιληφθεί το πραγματικό όφελος του IoT. Ένα από αυτά είναι η αυτοκινητοβιομηχανία η οποία από την πρώτη στιγμή υιοθέτησε τη συγκεκριμένη τεχνολογία. Μπορεί στην Ελλάδα να μην το βλέπουμε στην πράξη, αλλά σε ΗΠΑ και Δ. Ευρώπη τα περισσότερα οχήματα πωλούνται με ενσωματωμένη συνδεσιμότητα και (συνδρομητικές) υπηρεσίες υποστήριξης προς τον οδηγό (τεράστιο το όφελος στον επαγγελματικό κλάδο). Έτσι, όχι μόνο μπορεί να γίνει πρόβλεψη βλαβών και αντικατάσταση εξαρτημάτων (της μπαταρίας για παράδειγμα) αλλά η εταιρεία υποστήριξης μπορεί να ειδοποιήσει τον οδηγό ότι το αυτοκίνητό του είναι ξεκλείδωτο και να του το κλειδώσει από μακριά.

Σαφής ορισμός προβλήματος-ανάγκης

Γενικά υπάρχει μια μακροχρόνια διαμάχη μεταξύ των επιστημόνων σχετικά με την υγρασία του εσωτερικού χώρου και την αντιληπτή ποιότητα του εσωτερικού αέρα (IAQ) και τις σχετικές επιπτώσεις στην υγεία. Η αύξηση της υγρασίας του εσωτερικού αέρα μπορεί να επηρεάσει θετικά το αντιληπτό IAQ, τη συμπτωματολογία των ματιών και πιθανώς την απόδοση της εργασίας στο περιβάλλον του γραφείου και γενικότερα των σχολικών αιθουσών. Μελέτες εισπνοής σε ποντίκια δεν δείχνουν επιδείνωση του αισθητικού ερεθισμού στους αεραγωγούς λόγω χαμηλής υγρασίας. Ο αυξημένος σε υγρασία εσωτερικός αέρας φαίνεται να μειώνει τα ρινικά συμπτώματα σε ασθενείς που πάσχουν από σύνδρομο αποφρακτικής άπνοιας, ενώ δεν έχει εντοπιστεί σαφής βελτίωση στην παραγωγή φωνής, εκτός από εκείνους με φωνητική κόπωση. Τόσο η χαμηλή όσο και η υψηλή RH, και ίσως ακόμη καλύτερη απόλυτη υγρασία (υδρατμοί), ευνοεί τη μετάδοση και τη επιβίωση του ιού της γρίπης σε πολλές μελέτες, αλλά η σχέση μεταξύ θερμοκρασίας, υγρασίας και δυναμικής του ιού και αεροζόλ είναι πολύπλοκη, η οποία τελικά εξαρτάται από τον τύπο του ιού και τις φυσικές/χημικές του ιδιότητες.

Τα αιωρούμενα μικροσωματίδια διαμέτρου 1-10μm (γνωστά ως PM, Particulate Matter) αποτελούν από τους πιο επιβαρυντικούς ρύπους για την υγεία. Η μέτρησή τους με ακρίβεια είναι σχετικά δύσκολη και αρκετά δαπανηρή και δεν συνηθίζεται να γίνεται μέτρησή τους σε εσωτερικούς χώρους, παρόλο που στα σύγχρονα κτίρια οι ρύποι PM μπορεί να είναι περισσότεροι απ’ ότι στο εξωτερικό περιβάλλον. Αισθήτηρες με προέλευση την Κίνα, αρκετά αξιόπιστοι, μπορούν να ρίξουν αρκετά το κόστος ενός τέτοιου συστήματος παρακολούθησης του ιικού φορτίου.

Έρευνες έδειξαν ότι απαιτείται μελέτη της δυναμικής των σωματιδίων, των βακτηρίων και των ιών σε εσωτερικούς χώρους για τη βελτίωση της ποιότητας ζωής και με μεγαλύτερη έμφαση στον αντίκτυπο της απόλυτης υγρασίας. Ο «ξηρός (ή υγρός) αέρας» πρέπει να επαναπροσδιοριστεί για να γίνει ένας σημαντικός περιγραφέας IAQ.

ΣΧΕΔΙΑΣΗ

Το έργο θα αποτελείται από διάφορες τεχνολογίες οι οποίες όλες μαζί θα αποτελούν ένα σύστημα καταγραφής βεβαρημένης ατμόσφαιρας. Το σύστημα αυτό θα συμβάλλει στην παρακολούθηση του ιικού φορτίου στις σχολικές αίθουσες. Συγκεκριμένα:

Καταμέτρηση ατόμων

Θα καταγράφει πόσοι μαθητές βρίσκονται σε κάθε αίθουσα την κάθε στιγμή [θα χρησιμοποιηθεί ως παρουσιολόγιο]). Θα χρησιμοποιήσουμε δύο Υπέρυθρους Αισθητήρες Απόστασης οι οποίοι θα συνδέονται σε ένα Arduino Mega. Ο Α αισθητήρας θα τοποθετηθεί στην έξω πλευρά της τάξης ενώ ο Β στην μέσα πλευρά. Εάν ο Α αισθητήρας ενεργοποιηθεί πρώτος του Β σημαίνει ότι ένα άτομο εισήλθε μέσα στην αίθουσα. Αντίστοιχα εάν ενεργοποιηθεί πρώτα ο Β καταλαβαίνουμε πως ένα άτομο εξήλθε από την τάξη.

Έλεγχος αν η αίθουσα αερίζεται

Για να καταγράψουμε εάν η αίθουσα αερίζεται ελέγχουμε εάν ένα παράθυρο είναι ανοιχτό ή όχι. Η καταγραφή θα γίνει με την χρήση ενός μαγνητικού αισθητήρα (Magnetic Reed Switch), αποτελούμενος από δύο μέρη που συνδέονται σε ένα Arduino Mega. Το ένα τοποθετείται στο κούφωμα ενώ το άλλο αντίστοιχα στο παράθυρο. Όταν το παράθυρο ανοίξει, παύει να υπάρχει μαγνητισμός μεταξύ αυτών των δύο. Επομένως καταλαβαίνουμε πως το παράθυρο είναι ανοιχτό και η αίθουσα αερίζεται.

Καταγραφή ποιότητας και επιπέδου ρύπανσης αέρα

Για την καταγραφή της ποιότητας και του επιπέδου ρύπανσης αέρα θα χρησιμοποιηθούν δύο (2) αισθητήρες τα δεδομένα των οποίων θα αποστέλλονται στο Arduino.

Για την μέτρηση της ποιότητας του αέρα θα χρησιμοποιήσουμε έναν αισθητήρα Ποιότητας Αέρα (CCS811). Ο αισθητήρας καταγράφει τα επίπεδα διοξειδίου του άνθρακα (CO2) και πτητικών οργανικών ενώσεων (tVOC).

Για την μέτρηση του επιπέδου ρύπανσης του αέρα θα χρησιμοποιήσουμε έναν Particulate Matter Sensor PMS5003 ο οποίος ανιχνεύει τα μικροσωματίδια που είναι στην ατμόσφαιρα της αίθουσας. Γίνεται καταμέτρηση τριών διαστάσεων μικροσωματιδίων, όπως είναι τα PM1, PM2.5, PM10.

Καταγραφή θερμοκρασίας και υγρασίας αιθουσών

Όλες οι τιμές που θα καταγράφονται με τα παραπάνω συστήματα θα είναι προσβάσιμες μέσω διαδικτύου στην ιστοσελίδα www.thinkspeak.com καθώς θα χρησιμοποιηθεί η τεχνολογία Internet of Things (IoT). Οι τιμές αυτές μπορούν να επεξεργασθούν προκειμένου να δώσουν στοιχεία κατά πόσο επηρεάζει η ρύπανση των αιθουσών (ανάλογα με τις συνθήκες) τις απουσίες των μαθητών. Το σύστημα καταγραφής βεβαρημένης ατμόσφαιρας θα τοποθετηθεί σε 3 αίθουσες με διαφορετικό προσανατολισμό, προκειμένου να είναι δυνατή η σύγκριση δεδομένων.

## Πηγές

https://biztech.gr/τα-πραγματικά-οφέλη-του-internet-of-things/ (https://biztech.gr/%CF%84%CE%B1-%CF%80%CF%81%CE%B1%CE%B3%CE%BC%CE%B1%CF%84%CE%B9%CE%BA%CE%AC-%CE%BF%CF%86%CE%AD%CE%BB%CE%B7-%CF%84%CE%BF%CF%85-internet-of-thi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)

https://www.cnn.gr/ellada/story/247522/neotera-dedomena-pos-metadidetai-o-koronoios-se-kleistoys-xoroys-me-tin-omilia-i-tin-anapnoi

https://voultherm.gr/el/view/iaq-thermiki-anesi

https://eclass.upatras.gr/modules/document/file.php/ENV235/indoor_air_quality.ppt

https://nemertes.lis.upatras.gr/jspui/bitstream/10889/6099/3/Nimertis_Varotsou%28bio%29.pdf

https://scijinks.gov/air-quality/

https://www.eea.europa.eu/el/simata-eop-2010/simata-2013/arthra/poiotita-aera-esoterikon-choron

https://www.eea.europa.eu/el/simata-eop-2010/simata-2013/arthra/poiotita-aera-esoterikon-choron

https://www.lifo.gr/now/tech-science/internet-things-thayma-poy-erhetai-periehei-megales-antifaseis

https://www.skai.gr/news/ygeia/koronoios-poso-syxna-aerizoume-an-den-mporoume-na-afisoume-monima-anoikta-parathyra

https://www.skai.gr/news/ygeia/koronoios-poso-syxna-aerizoume-an-den-mporoume-na-afisoume-monima-anoikta-parathyra

https://www.thingiverse.com/thing:2320020

https://www.vita.gr/2009/06/06/body-mind/aiwroymena-swmatidia-oi-aoratoi-exthroi-ths-ygeias-mas/

Ruzer, L. & Harley, N. (2005). Aerosols handbook, measurement, dosimetry and health effects

Wolkoff (2018). Indoor air humidity, air quality, and health – An overview. International Journal of Hygiene and Environmental Health 221, 376–390.

Σπηλιωτόπουλος, Γ. (2019). Σύστημα IoT χαμηλού κόστους για παρακολούθηση ποιότητας αέρα σε εσωτερικούς χώρους (Διπλωματική Εργασία). Πάτρα: ΕΑΠ.

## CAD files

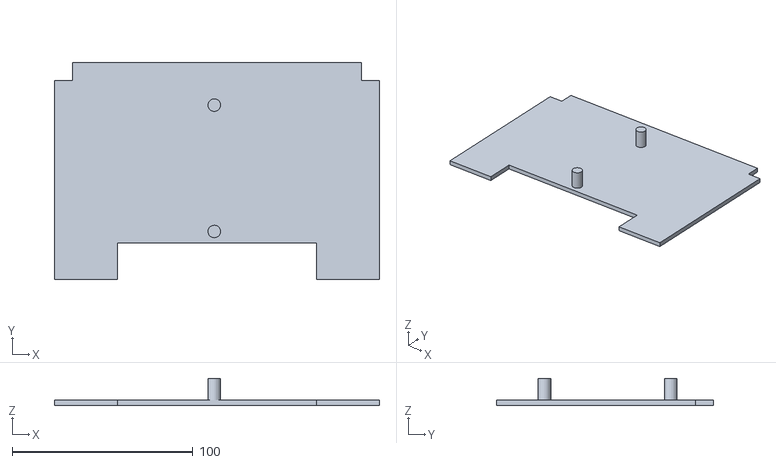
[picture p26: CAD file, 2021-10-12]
code/3d files/VIRUSBOTS sensor holder.stl
180.0 x 120.0 x 15.0

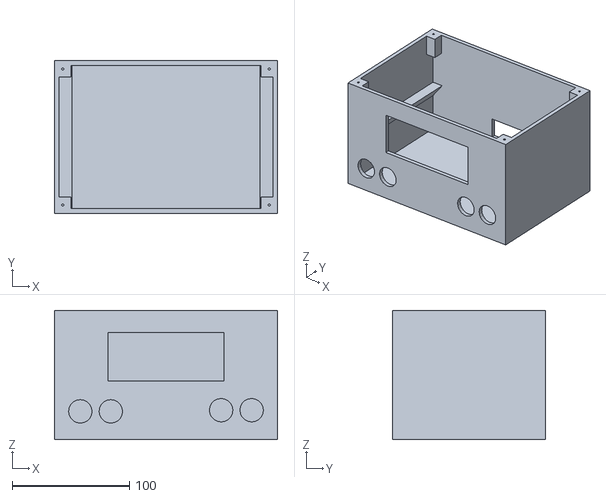
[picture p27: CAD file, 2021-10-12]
code/3d files/VIRUSBOTS case.stl
190.0 x 130.0 x 110.0

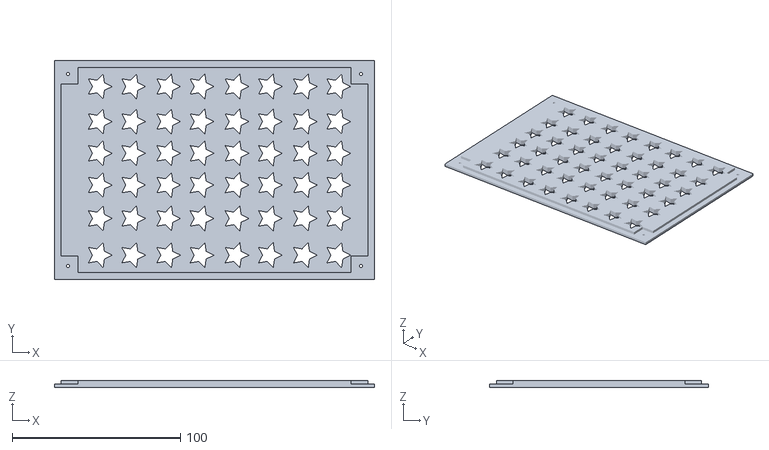
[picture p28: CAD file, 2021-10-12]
code/3d files/VIRUSBOTS case cap.stl
190.0 x 130.0 x 4.00

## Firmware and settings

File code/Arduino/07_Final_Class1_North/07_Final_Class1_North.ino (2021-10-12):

// 07. Τελική έκδοση με βελτιώσεις - 1η αίθουσα - βόρεια

#include "PMS.h"
#include "DHT.h"

#include <LiquidCrystal_I2C.h>
#include <Wire.h>

#include <NewPing.h>

#include "SparkFunCCS811.h"

#include "WiFiEsp.h"

#define DHTPIN 13
#define DHTTYPE DHT11

#define MAX_DISTANCE 70 // Η μέγιστη απόσταση (σε cm) που ελέγχουν οι αισθητήρες

#define WINDOW_SENSOR_PIN 7

#define CCS811_ADDR 0x5B //Default I2C Address
//#define CCS811_ADDR 0x5A //Alternate I2C Address

DHT dht(DHTPIN, DHTTYPE);

PMS pms(Serial1);
PMS::DATA data;

unsigned long currentTime;
unsigned long previousTime1 = 0;
unsigned long previousTime2 = 0;

NewPing sonar1 = NewPing(9, 8, MAX_DISTANCE);
NewPing sonar2 = NewPing(11, 10, MAX_DISTANCE);

LiquidCrystal_I2C lcd(0x27, 20, 4);  // οθόνη LCD 20 χαρακτήρων και 4 γραμμών στη διεύθυνση 0x27

CCS811 mySensor(CCS811_ADDR);

// Initialize the Ethernet client object
WiFiEspClient client;

int sensor1 = 0;
int sensor2 = 0;

unsigned long t1 = 0;
unsigned long t2 = 0;

int distance1 = 0;
int distance2 = 0;
int visitors = 0;

int pmsData10 = 0;
int pmsData25 = 0;
int pmsData100 = 0;

int windowState;
int winst=0;

int co2 = 0;
int tvoc = 0;

float h = 0.0;
float t = 0.0;

// Κωδικοί WiFi ΑΙΘΟΥΣΑ 1 ΒΟΡΕΙΑ
char ssid[] = "ΧΧΧΧΧΧΧΧ";     // WiFi SSID (name)
char pass[] = "ΧΧΧΧΧΧΧΧ";     // WiFi password
int status = WL_IDLE_STATUS;

// IP του thingspeak.com 
char server[] = "184.106.153.149"; 
// Write API Key του λογαριασμού στο thingspeak
char writeKey[] = "ΧΧΧΧΧΧΧΧΧΧΧΧΧΧΧΧ";

void setup()
{
  dht.begin();

  Serial.begin(115200);
  Serial1.begin(9600);
  Serial.println("hi");

  // Εδώ χρησιμοποιούμε το PMS5003 σε passive mode, έτσι ώστε να διαβάζουμε τις μετρήσεις του όταν απαιτείται
  pms.passiveMode();    // Switch PMS5003 to passive mode
  pms.wakeUp();

  lcd.init();
  lcd.backlight();
  lcd.setCursor(0,0);
  lcd.print("1st EPAL of Trikala");

  pinMode(WINDOW_SENSOR_PIN, INPUT_PULLUP); // set arduino pin to input pull-up mode

  // ccs811
  Wire.begin(); // Initialize I2C Hardware

  if( mySensor.begin() == false )
  {
    lcd.println("CCS811 Error...");
    while(true);  // τέλος...
  }

  // Αρχικοποίηση του serial2 για το ESP module
  // ΠΡΟΣΟΧΗ: TX->RX3 ΚΑΙ RX->TX3
  Serial2.begin(115200);
  // initialize ESP module
  WiFi.init(&Serial2);

  // έλεγχος για το ESP8266
  if( WiFi.status() == WL_NO_SHIELD )
  {
    Serial.println("WiFi shield not present");
    while(true);  // τέλος...
  }

  // σύνδεση στο WiFi
  while( WiFi.status() != WL_CONNECTED )
  {
    lcd.setCursor(0,2);
    lcd.print("Connecting...       ");    
    Serial.print("Attempting to connect to: ");
    Serial.println(ssid);
    status = WiFi.begin(ssid, pass);
  }

  Serial.println("You're connected to the wifi");
  Serial.println();
  lcd.setCursor(0,3);
  lcd.print("Connected!          ");
  delay(2000);
}

void loop()
{
  currentTime = millis();
  
  // Μέτρηση επισκεπτών
  delay(33);
  distance1 = sonar1.ping_cm();
  delay(33);
  distance2 = sonar2.ping_cm();
  
  if( distance1 > 0 && distance1 < MAX_DISTANCE )
  {
    sensor1 = 1;
    t1 = millis();
  }
  else
  {
    sensor1 = 0;
  }

  if( distance2 > 0 && distance2 < MAX_DISTANCE )
  {
    sensor2 = 1;
    t2 = millis();
  }
  else
  {
    sensor2 = 0;
  }

  if( sensor1 == 0 && sensor2 == 0 )
  {
    if( t1 > 0 && t2 > 0 )
    {
      if( t2 > t1 )
      {
        visitors++;
      }
      else if( t1 > t2 )
      {
        if( visitors > 0 )
          visitors--;
      }
      t1 = t2 = 0;
    }
    if( currentTime-t1 > 2000 ) t1=0;
    if( currentTime-t2 > 2000 ) t2=0;
  }
  
  if( currentTime - previousTime1 >= 5000 )
  {
    // διάβασμα CCS811
    if( mySensor.dataAvailable() )
    {
      mySensor.readAlgorithmResults();
      co2 = mySensor.getCO2();
      tvoc = mySensor.getTVOC();
    }

    // διάβασμα DHT11
    h = dht.readHumidity();
    t = dht.readTemperature();

    // διάβασμα PMS5003
    pms.requestRead();  
    if( pms.readUntil(data) )
    {
      pmsData10 = data.PM_AE_UG_1_0;
      pmsData25 = data.PM_AE_UG_2_5;
      pmsData100 = data.PM_AE_UG_10_0;
    }
    else
    {
      //Serial.println("No PMS data.");
    }
    
    Serial.print("PM 1.0 (ug/m3): ");
    Serial.println(pmsData10);
    Serial.print("PM 2.5 (ug/m3): ");
    Serial.println(pmsData25);
    Serial.print("PM 10.0 (ug/m3): ");
    Serial.println(pmsData100);
    Serial.println();
    
    Serial.print("CO2: ");
    Serial.println(co2);
    Serial.print("tVOC: ");
    Serial.println(tvoc);
    Serial.println();   
     
    Serial.print("Temperature: ");
    Serial.println(t);
    Serial.print("Humidity: ");
    Serial.println(h);
    Serial.println();

    windowState = digitalRead(WINDOW_SENSOR_PIN);
    if (windowState == HIGH)
    {
      Serial.println("The window is open");
      winst=1;
    }
    else
    {
      Serial.println("The window is closed");
      winst=0;
    }
    Serial.print("Visitors: ");
    Serial.println(visitors);
    Serial.println();

    lcd.setCursor(0,1);
    lcd.print("PM2.5=");
    lcd.setCursor(6,1);
    lcd.print("    ");
    lcd.setCursor(6,1);
    lcd.print(pmsData25);
    
    lcd.setCursor(10,1);
    lcd.print("PM10=");
    lcd.setCursor(15,1);
    lcd.print("     ");
    lcd.setCursor(15,1);
    lcd.print(pmsData100);

    lcd.setCursor(0, 2);
    lcd.print("CO2=");
    lcd.print("      ");
    lcd.setCursor(4, 2);
    lcd.print(co2);

    lcd.setCursor(10, 2);
    lcd.print("tVOC=");
    lcd.print("    ");    
    lcd.setCursor(15, 2);
    lcd.print(tvoc);
    
    lcd.setCursor(0, 3);
    lcd.print("T=");
    lcd.print("      ");
    lcd.setCursor(2, 3);
    lcd.print(t);
    lcd.print("oC ");
    lcd.setCursor(10, 3);
    lcd.print("H=");
    lcd.print("      ");    
    lcd.setCursor(12, 3);
    lcd.print(h);
    lcd.print("%  ");

    Serial.println("--------------------------------");
    
    previousTime1 = currentTime;
  }
  
  // κάθε 16 sec,
  if( currentTime - previousTime2 >= 16000 )
  {
    // Συνδέσου με το thingspeak για αποστολή των δεδομένων 
    Serial.println("Starting connection to thingspeak..."); 
    client.stop();
    if( client.connect(server, 80) ) 
    { 
      Serial.println("Connected to thingspeak.com"); 
      // Δημιουργία του αιτήματος HTTP, όπως απαιτεί το thingspeak.com 
      String request= "GET /update?key="; 

      request += writeKey; 
      
      request += "&field1="; 
      request += String(pmsData25); 
  
      request += "&field2="; 
      request += String(pmsData100); 
      
      request += "&field3="; 
      request += String(co2); 
      
      request += "&field4="; 
      request += String(tvoc); 
      
      request += "&field5="; 
      request += String(visitors); 
      
      request += "&field6="; 
      request += String(winst);
       
      request += "&field7="; 
      request += String(t); 
  
      request += "&field8="; 
      request += String(h); 
    
      Serial.println(request); 
      // Εμφάνιση στο serial monitor για debugging 
      // Αποστολή του αιτήματος client.println(request); 
      // client.println("GET /asciilogo.txt HTTP/1.1"); 
      client.println(request);
      client.println("Host: 184.106.153.149");
    
      client.println("Connection: close"); 
      client.println(); 
    }
    previousTime2 = currentTime;
  }
}
